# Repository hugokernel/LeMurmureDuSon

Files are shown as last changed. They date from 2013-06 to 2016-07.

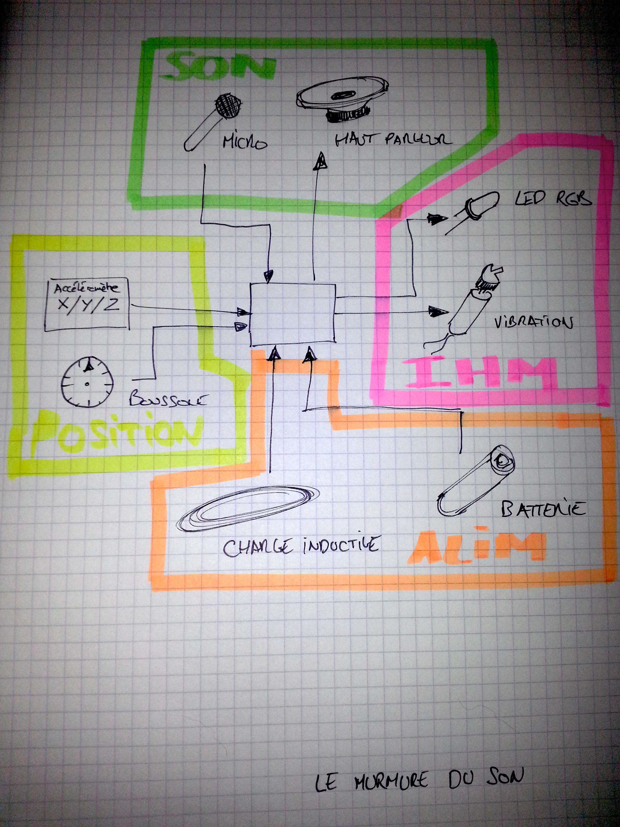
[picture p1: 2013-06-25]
doc/overview.jpg

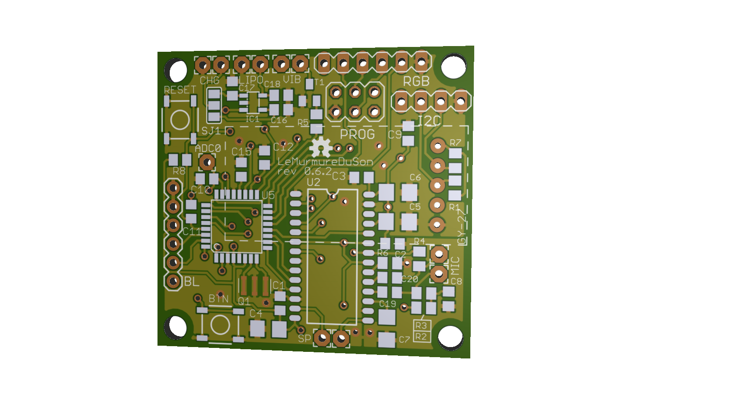
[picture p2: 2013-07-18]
export/img/0.6.2/gerber.png

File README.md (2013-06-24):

LeMurmureDuSon
==============

Projet de l'équipe nº1 du Museolab 2013 : Le murmure du son

Développement d'un post'it vocal sous la forme d'un cube

Caractéristiques
----------------

- 1 message enregistrable par face
- 1 texture différente par face
- Chaque message est limité à 6 secondes
- Possibilité d'enregistrement d'un nouveau message sur chaque face
- Charge par induction
- Détection de la face exposée vers le haut (accéléromètre)
- Le cube est translucide
- 1 vibreur
- Éclairage par 1 ou plusieurs led RGB
- Sur batterie
- Réalisable en impression 3D

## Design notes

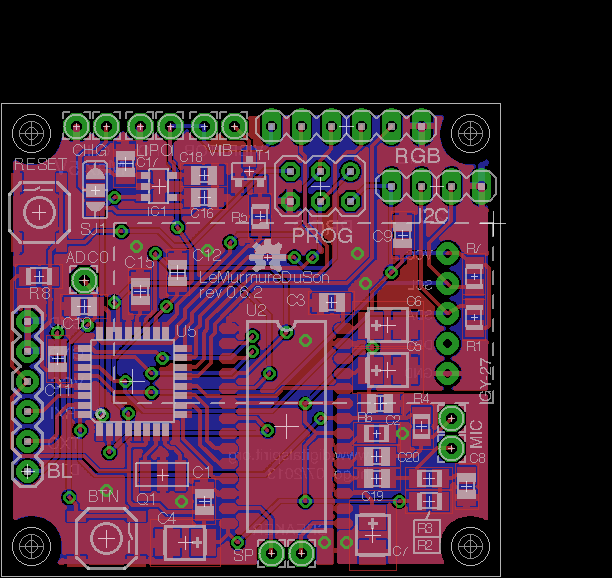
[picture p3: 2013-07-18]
export/img/0.6.2/pcb.png

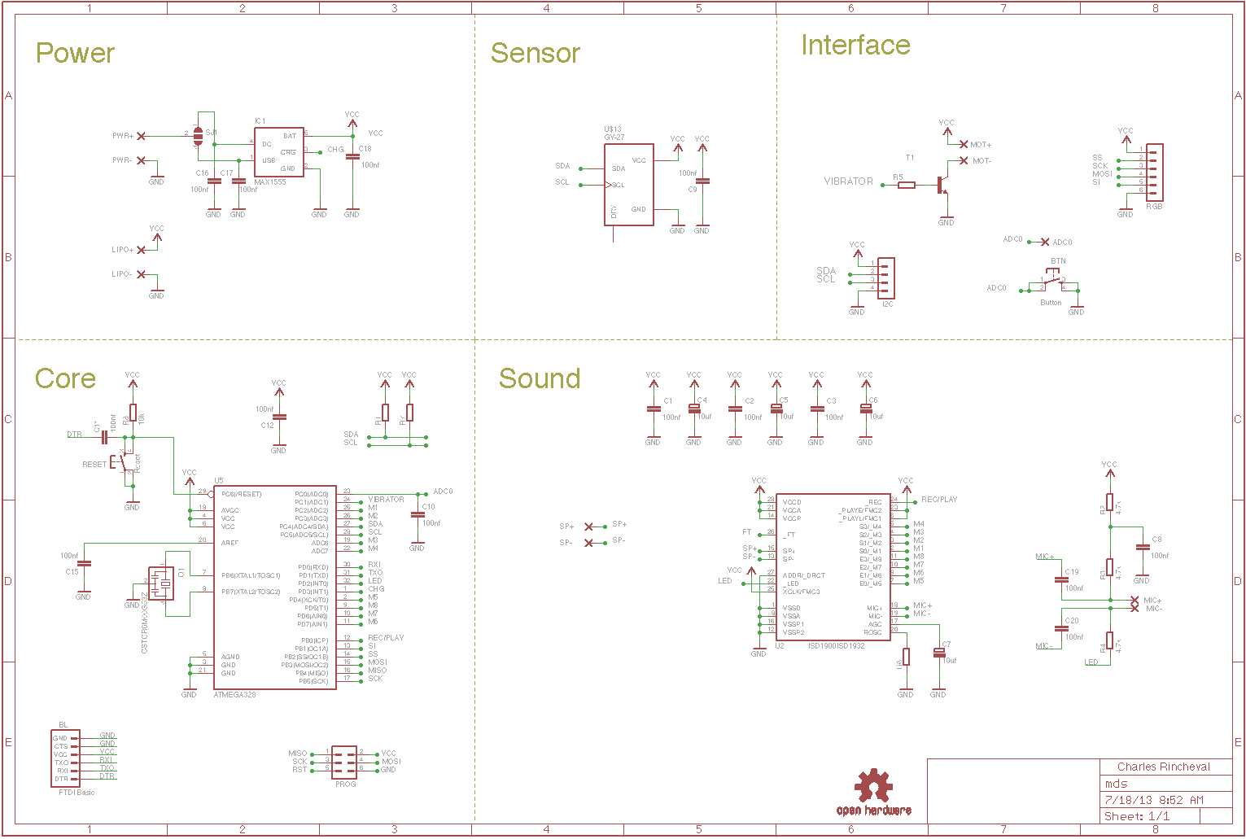
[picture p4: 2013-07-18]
export/img/0.6.2/schema.png

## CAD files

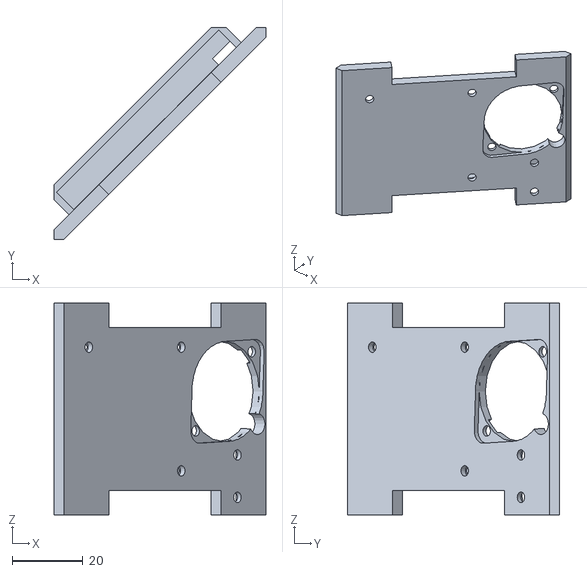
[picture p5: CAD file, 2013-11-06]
export/stl/support.stl
60.0 x 60.0 x 60.0

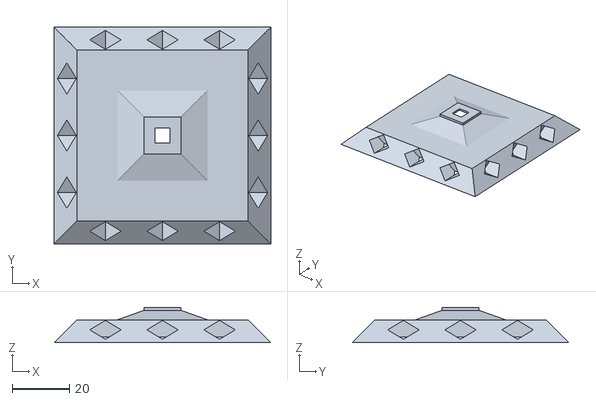
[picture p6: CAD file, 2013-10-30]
export/stl/4.stl
76.0 x 76.0 x 12.4

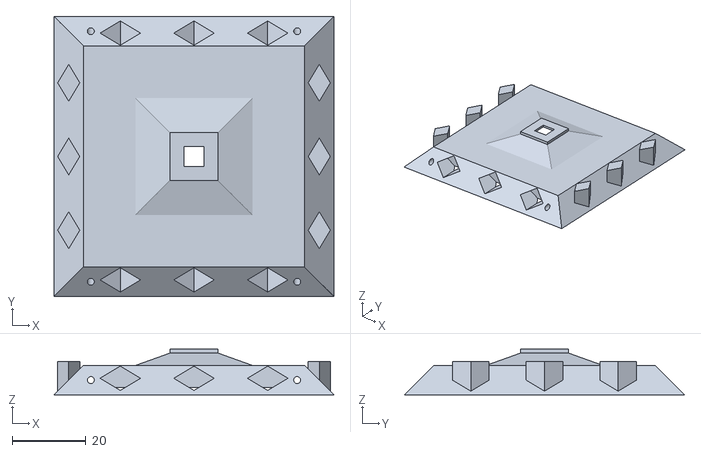
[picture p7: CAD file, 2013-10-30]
export/stl/2.stl
76.0 x 76.0 x 12.4

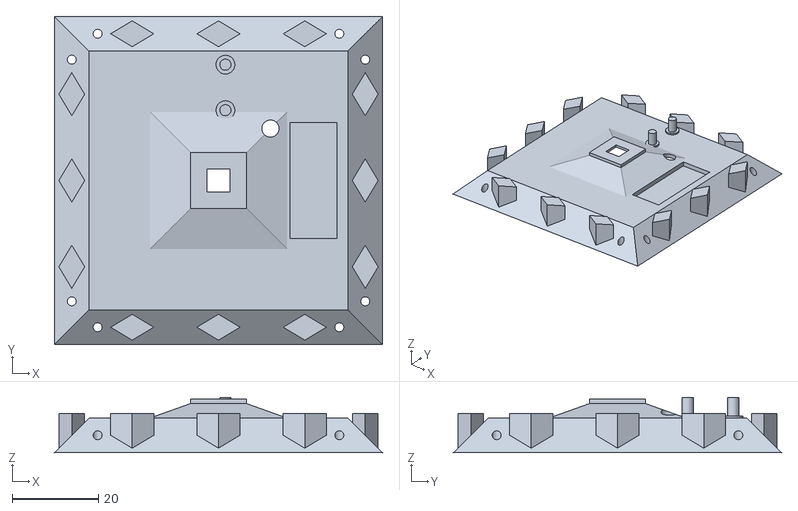
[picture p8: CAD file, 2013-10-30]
export/stl/0.stl
76.0 x 76.0 x 12.8

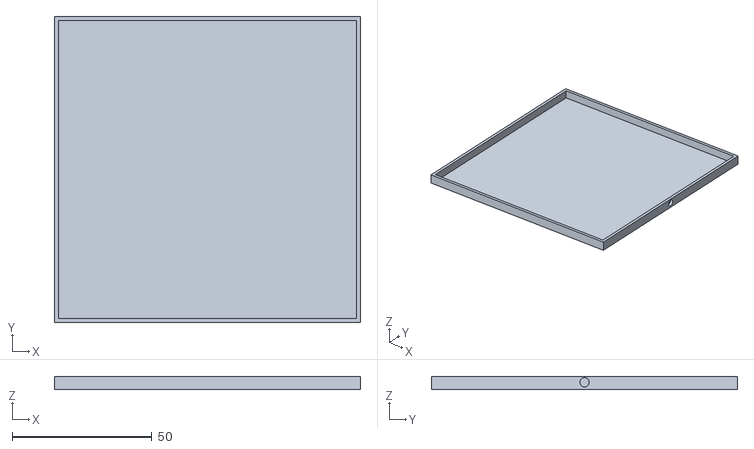
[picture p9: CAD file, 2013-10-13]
export/stl/base_enveloppe_cable.stl
109.4 x 109.4 x 4.70

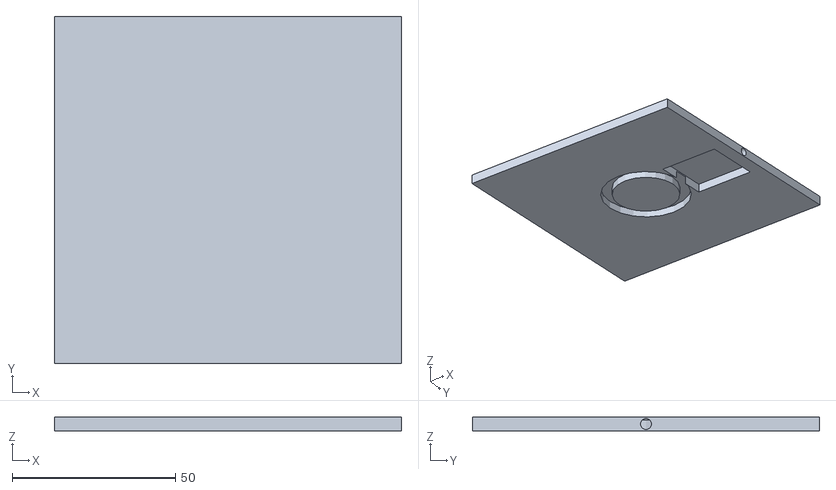
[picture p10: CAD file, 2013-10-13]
export/stl/base_plate_cable.stl
106.4 x 106.4 x 4.20

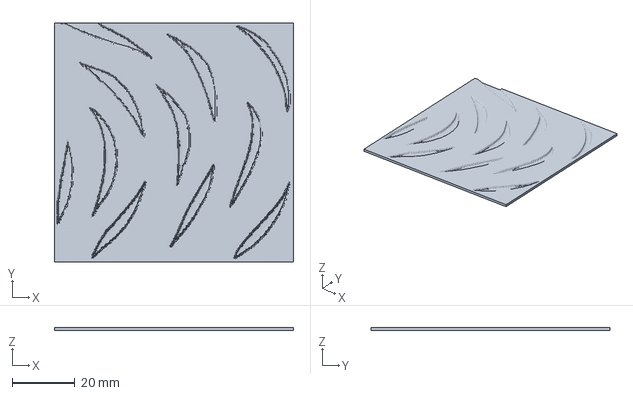
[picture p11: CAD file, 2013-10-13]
export/stl/pattern_5.amf
76.0 x 76.0 x 1.00 mm

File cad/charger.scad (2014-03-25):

use <cube.scad>

SIZE = 76;

coeff = 1.4;
thickness = 4.2;
size = SIZE * coeff;

module cable() {
    // Cable
    translate([SIZE / 2, 0, 0]) {
        rotate([0, 90, 0]) {
            cylinder(r = thickness / 2 - thickness * 0.1, h = 20);
        }
    }
}

module usb() {
    length = 8;
    width = 7.2;
    thickness = 2.9;

    // Usb
    translate([size / 2 - width / 2 + 0.001, 0, 0]) {//-thickness / 2 - 0.01]) {
        cube(size = [width, length, thickness], center = true);
    }
}

module enveloppe(usb = true) {
    base_thickness = 0.5;
    gain = 3;
    sizee = size + gain;
    clear = 0;
    translate([0, 0, - thickness / 2 - base_thickness / 2]) {
        cube(size = [sizee, sizee, base_thickness], center = true);
    }

    translate([0, 0, 0]) {
        difference() {
            cube(size = [sizee, sizee, thickness], center = true);
            translate([0, 0, 0.1]) {
                cube(size = [size + clear, size + clear, thickness], center = true);
            }

            translate([gain / 2, 0, 0]) {
                if (usb) {
                    usb();
                } else {
                    cable();
                }
            }
        }
    }
}

module base(usb = true) {

    module plate() {
        difference() {
            cube(size = [size, size, thickness], center = true);

            //translate([0, 0, -thickness / 2 - 0.01]) {
            translate([0, 0, -3]) {
                coil(hole = false, height = thickness);
            }

            //translate([33, 0, -thickness / 2 - 0.01]) {
            translate([33, 0, -0.3]) {
                cube(size = [28, 25, thickness], center = true);
            }

            if (usb) {
                usb();
            } else {
                cable();
            }
        }
    }

    plate();
    //enveloppe();
}

intersection() {
    /*
    translate([50, 0, 0]) {
        cube([40, 40, 20], center = true);
    }
    */
    //base();
    enveloppe();
}

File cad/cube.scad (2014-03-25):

use <lib/Spiff.scad>;
use <lib/mx.scad>;

$fn = 20;

SIZE = 76;
RIDGE_WIDTH = 8;

THICKNESS = 3;

HOLE_DIAMETER = 2 + .1;

ELEC_WIDTH = 42.3;
ELEC_LENGTH = 40;
ELEC_THICKNESS = 0.8;

ELEC_SUPPORT_WIDTH = 37;
ELEC_SUPPORT_LENGTH = 35;
ELEC_HOLE_DIAMETER = 3;

GY27_WIDTH = 15.55;
GY27_LENGTH = 32.55;
GY27_THICKNESS = 1.6;
GY27_HEIGHT = 3.8;
GY27_HOLE_DIAMETER = 3;

REFLECTOR_HEIGHT = 12;

DEBUG = false;

module coil(hole = true, height = 1.7) {
    ediameter = 39;
    idiameter = 29.1;
    difference() {
        cylinder(r = ediameter / 2, h = height);

        translate([0, 0, -2]) {
            cylinder(r = idiameter / 2, h = 10);
        }
    }

    if (hole) {
        translate([(ediameter - (ediameter - idiameter) / 2) / 2, 0, 0]) {
            cylinder(r = 2, h = 12);
        }
    }
}

module charger() {
    cube(size = [9.9, 24.5, 4], center = true);
}

module gy27(support = false) {
    positions = [
        [GY27_WIDTH / 2 - 2.5, GY27_LENGTH / 2 - 3, 0],
        [-GY27_WIDTH / 2 + 2.5, GY27_LENGTH / 2 - 3, 0],
    ];

    if (support) {
        for (pos = positions) {
            translate([pos[0], pos[1], pos[2] - 0.25]) {
                cylinder(r = GY27_HOLE_DIAMETER / 2 + 0.7, h = 0.5, center = true);
                translate([0, 0, 2]) {
                    cylinder(r = GY27_HOLE_DIAMETER / 2 - 0.2, h = 5, center = true);
                }
            }
        }
    } else {
        difference() {
            cube(size = [GY27_WIDTH, GY27_LENGTH, GY27_THICKNESS], center = true);
            for (pos = positions) {
                translate(pos) {
                    cylinder(r = GY27_HOLE_DIAMETER / 2, h = 10, center = true);

                    if ($children) {
                        for (i = [0 : $children - 1]) {
                            child(0);
                        }
                    }
                }
            }
        }
    }
}

module electronic(version = 1, diff = false) {
    module bluetooth() {
        width = 10;
        length = 15;
        translate([-ELEC_WIDTH / 2, -ELEC_LENGTH / 2 + 16 / 2 - 0.5, 0]) {
            cube(size = [width, length, ELEC_THICKNESS], center = true);
        }
    }

    module holes() {
        for(pos = [
            [ELEC_SUPPORT_WIDTH / 2, ELEC_SUPPORT_LENGTH / 2, -5, 2],
            [-ELEC_SUPPORT_WIDTH / 2, ELEC_SUPPORT_LENGTH / 2, -5, 2],
            [ELEC_SUPPORT_WIDTH / 2, -ELEC_SUPPORT_LENGTH / 2, -5, 2],
            [-ELEC_SUPPORT_WIDTH / 2, -ELEC_SUPPORT_LENGTH / 2, -5, 1],
        ]) {
            if (pos[3] >= version) {
                translate([pos[0], pos[1], -10]) {
                    cylinder(r = ELEC_HOLE_DIAMETER / 2, h = 10);
                }

                if ($children) {
                    translate([pos[0], pos[1], 0]) {
                        child(0);
                    }
                }
            }
        }
    }

    module body() {
        cube(size = [ELEC_WIDTH, ELEC_LENGTH, ELEC_THICKNESS], center = true);
        if (version == 2) {
            bluetooth();
        }
    }

    if (diff) {
        //body();
        holes() {
            if ($children) {
                child(0);
            }
        };
    } else {
        difference() {
            body();
            holes();
        }
    }
}

LIPO_WIDTH = 40;
LIPO_LENGTH = 65;
LIPO_THICKNESS = 7;

module lipo() {
    cube(size = [LIPO_LENGTH, LIPO_WIDTH, LIPO_THICKNESS], center = true);
}

SPEAKER_DIAMETER = 28.5;
module speaker() {
    thickness = 5;
    clear = 0.5;

    module holes() {
        for (pos = [
            [31.7 / 2, 0, 0],
            [-31.7 / 2, 0, 0],
        ]) {
            translate(pos) {
                child(0);
            }
        }
    }

    hull() {
        cylinder(r = SPEAKER_DIAMETER / 2, h = thickness, center = true);
        holes() {
            cylinder(r = 3.5, h = thickness, center = true);
        }
    }

    holes() {
        child(0);
    }
}

module vibrator() {
    translate([29, -25, 0]) {
        cylinder(r = 1.5, h = 10, center = true);
        translate([0, 12, 0]) {
            cylinder(r = 1.5, h = 10, center = true);
        }

        hull() {
            translate([0, 0, -2]) {
                cylinder(r = 3.5, h = 5, center = true);
            }

            translate([0, 12, -2]) {
                cylinder(r = 3.5, h = 5, center = true);
            }
        }
    }
}

module support() {

    thickness = 4;
    height = SIZE - RIDGE_WIDTH * 2;
    size = sqrt(pow(height, 2) + pow(height, 2));
    ear = 20;

    lipo_support_thickness = 3;

    module lipo_support() {
        translate([0, -LIPO_WIDTH / 2 - lipo_support_thickness / 2 + 2, - thickness / 2 - LIPO_THICKNESS / 2]) {
            cube(size = [LIPO_LENGTH + thickness, lipo_support_thickness + thickness, LIPO_THICKNESS + thickness], center = true);
        }
    }

    module _speaker() {
        translate([25, 5, 6]) {
            cylinder(r = SPEAKER_DIAMETER / 2, h = 50, center = true);
            rotate([0, 0, 45]) {
                color("ORANGE") speaker() {
                    child(0);
                }
            }

            /*
            translate([8, SPEAKER_DIAMETER / 2 + 5, 0]) {
                cylinder(r = 3, h = 50, center = true);
            }
            */
        }

        translate([37, -SPEAKER_DIAMETER / 2 + 10, 0]) {
            cylinder(r = 3, h = 50, center = true);
        }
    }

/*
    module _gy27(support = false) {
        rotate([90, 45, 0]) {
            translate([21, -12, height / 2]) {
                gy27(support);
            }
        }
    }
*/
    rotate([90, 0, 45]) {
        difference() {

            union() {
                // Helper
                //%cube(size = [size, height, 1], center = true);

                cube(size = [size, height - REFLECTOR_HEIGHT - 2, thickness], center = true);
                for (pos = [
                    [size / 2 - ear / 2, height / 2 - ear / 2, 0],
                    [-size / 2 + ear / 2, height / 2 - ear / 2, 0],
                    [size / 2 - ear / 2, -height / 2 + ear / 2, 0],
                    [-size / 2 + ear / 2, -height / 2 + ear / 2, 0]
                ]) {
                    translate(pos) {
                        cube(size = [ear, ear, thickness], center = true);
                    }
                }

                if (DEBUG) {
                    translate([-12, 0, thickness]) {
                        color("RED") electronic(2);
                    }
                }

                if (DEBUG) {
                    translate([0, 0, - thickness / 2 - LIPO_THICKNESS / 2]) {
                        //%color("GREY") lipo();
                    }
                }

                lipo_support();

                //_speaker();
            }

            for (pos = [
                [0, SIZE / 2 - RIDGE_WIDTH / 2, 0, 45, 90],
                [0, - SIZE / 2 + RIDGE_WIDTH / 2, 0, -45, 90],
                [0, SIZE / 2 - RIDGE_WIDTH / 2, 0, -45, 90],
                [0, - SIZE / 2 + RIDGE_WIDTH / 2, 0, 45, 90]
            ]) {
                rotate([pos[3], 0, pos[4]]) {
                    translate([pos[0], pos[1], pos[2]]) {
                        cube(size = [SIZE, RIDGE_WIDTH, SIZE], center = true);
                    }
                }
            }

            translate([-12, 0, thickness]) {
                electronic(2, true) {
                    union() {
                        translate([0, 0, -4.9]) {
                            m3_nut();
                        }
                    }
                }
            }

            translate([0, 0, - thickness / 2 - LIPO_THICKNESS / 2 - .005]) {
                lipo();
            }

            translate([0, 0, -3]) {
                _speaker() {
                    union() {
                        cylinder(r = 1.5, h = 50, center = true);
                        translate([0, 0, -4.9]) {
                            m3_nut();
                            //cylinder(r = 3.5, h = 5, center = true);
                        }
                    }
                }
            }

            vibrator();
        }
    }
}

NOTHING = -1;
MALE = true;
FEMALE = false;

module front(index, mark, connection) {
    edge_size = SIZE / 2 * sqrt(2);

    module _charger() {
        rotate([0, 0, -45]) {
            translate([22, 0, 8.5]) {
                scale([1.1, 1.1, 1]) {
                    charger();
                }
            }
        }
    }

    module plot(add, substract = true) {
        width = 4;
        length = 10;
        //height = 8;
        height = 5;

        clear = 0.4;
        clear_height = 8;
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

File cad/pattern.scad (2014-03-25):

$fn = 20;

SIZE = 76;
THICKNESS = 1;

sizes = [
    [ 76.3, 76.5 ],     // 0
    [ 76.5, 76.2 ],     // 1
    [ 77.94, 77.94 ],   // 2
    [ 77.94, 77.94 ],   // 3
    [ 77.94, 76 ],      // 4
    [ 77.94, 76 ],      // 5
];

RIDGE_WIDTH = 8;
HOLE_DIAMETER = 2 + .5;

module holes() {
    rotate([0, 0, 45]) {
        for(pos = [
            [SIZE / 2 - RIDGE_WIDTH - 2, SIZE / 2 - RIDGE_WIDTH / 2, 0],
            [-SIZE / 2 + RIDGE_WIDTH + 2, SIZE / 2 - RIDGE_WIDTH / 2, 0],
            [SIZE / 2 - RIDGE_WIDTH - 2, -SIZE / 2 + RIDGE_WIDTH / 2, 0],
            [-SIZE / 2 + RIDGE_WIDTH + 2, -SIZE / 2 + RIDGE_WIDTH / 2, 0],
        ]) {
            translate(pos) {
                cylinder(r = HOLE_DIAMETER / 2, h = 100, center = true);

                if ($children) {
                    for (i = [0 : $children - 1]) {
                        child(0);
                    }
                }
            }
        }
    }
}

module bump(index, size = SIZE, thick = THICKNESS) {
    stl_width = 300;
    stl_thickness = 10;
    thickness = 1;

    coeff_w = stl_width / sizes[index][0];
    coeff_l = stl_width / sizes[index][1];
    coeff_t = stl_thickness / thick;

    translate([stl_width / coeff_w / 2, stl_width / coeff_l / 2, thickness / 2]) {
        scale([1 / coeff_w, 1 / coeff_l, 1 / coeff_t]) {
            import(str("pattern/", index, ".stl"));
        }
    }

    if (index == 5) {
        translate([0, 0, thickness / 2 - 0.4]) {
            cube(size = [sizes[index][0], sizes[index][1], 0.2], center = true);
        }
    } else {
        translate([0, 0, thickness / 2 - 0.5]) {
            cube(size = [sizes[index][0], sizes[index][1], 1], center = true);
        }
    }
}



module faces(which = -1, offset = 30) {

    nut_head_diameter = 4.6; // Before : 4: serré, 5: too large
    nut_head_height = 1.3;

    offset = offset + SIZE / 2;

    difference() {
        for (data = [
            [ 0, [0, 0, -offset],   [180, 0, 0], "RED" ],
            [ 1, [0, 0, offset],    [0, 0, 0]   ],
            [ 2, [offset, 0, 0],    [0, 90, 0], "BLUE" ],
            [ 3, [-offset, 0, 0],   [0, -90, 0] ],
            [ 4, [0, -offset, 0],   [90, 0, 0]  ],
            [ 5, [0, offset, 0],    [-90, 0, 0] ]
        ]) {
            if (which == -1 || which == data[0]) {
                translate(data[1]) {
                    rotate(data[2]) {
                        //color(data[3])
                        bump(data[0]);
                    }
                }
            }
        }

        rotate([0, 0, 45]) {
            holes() {
                if (which == 0) {
                    translate([0, 0, -(SIZE / 2 + nut_head_height + THICKNESS)]) {
                        cylinder(r = nut_head_diameter / 2, h = 2);
                    }
                } else if (which == 1) {
                    translate([0, 0, SIZE / 2 - nut_head_height + THICKNESS]) {
                        cylinder(r = nut_head_diameter / 2, h = 2);
                    }
                }
            }
        }
    
        if (which == 1) {
            // Mic hole
            translate([0, -20, 0]) {
                cylinder(r = 2, h = 200);
            }
        }
    }
}

//bump(1, SIZE);

%cube(size = [SIZE, SIZE, SIZE], center = true);

faces(4, 0);

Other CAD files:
export/stl/1.stl
export/stl/5.stl
export/stl/3.stl

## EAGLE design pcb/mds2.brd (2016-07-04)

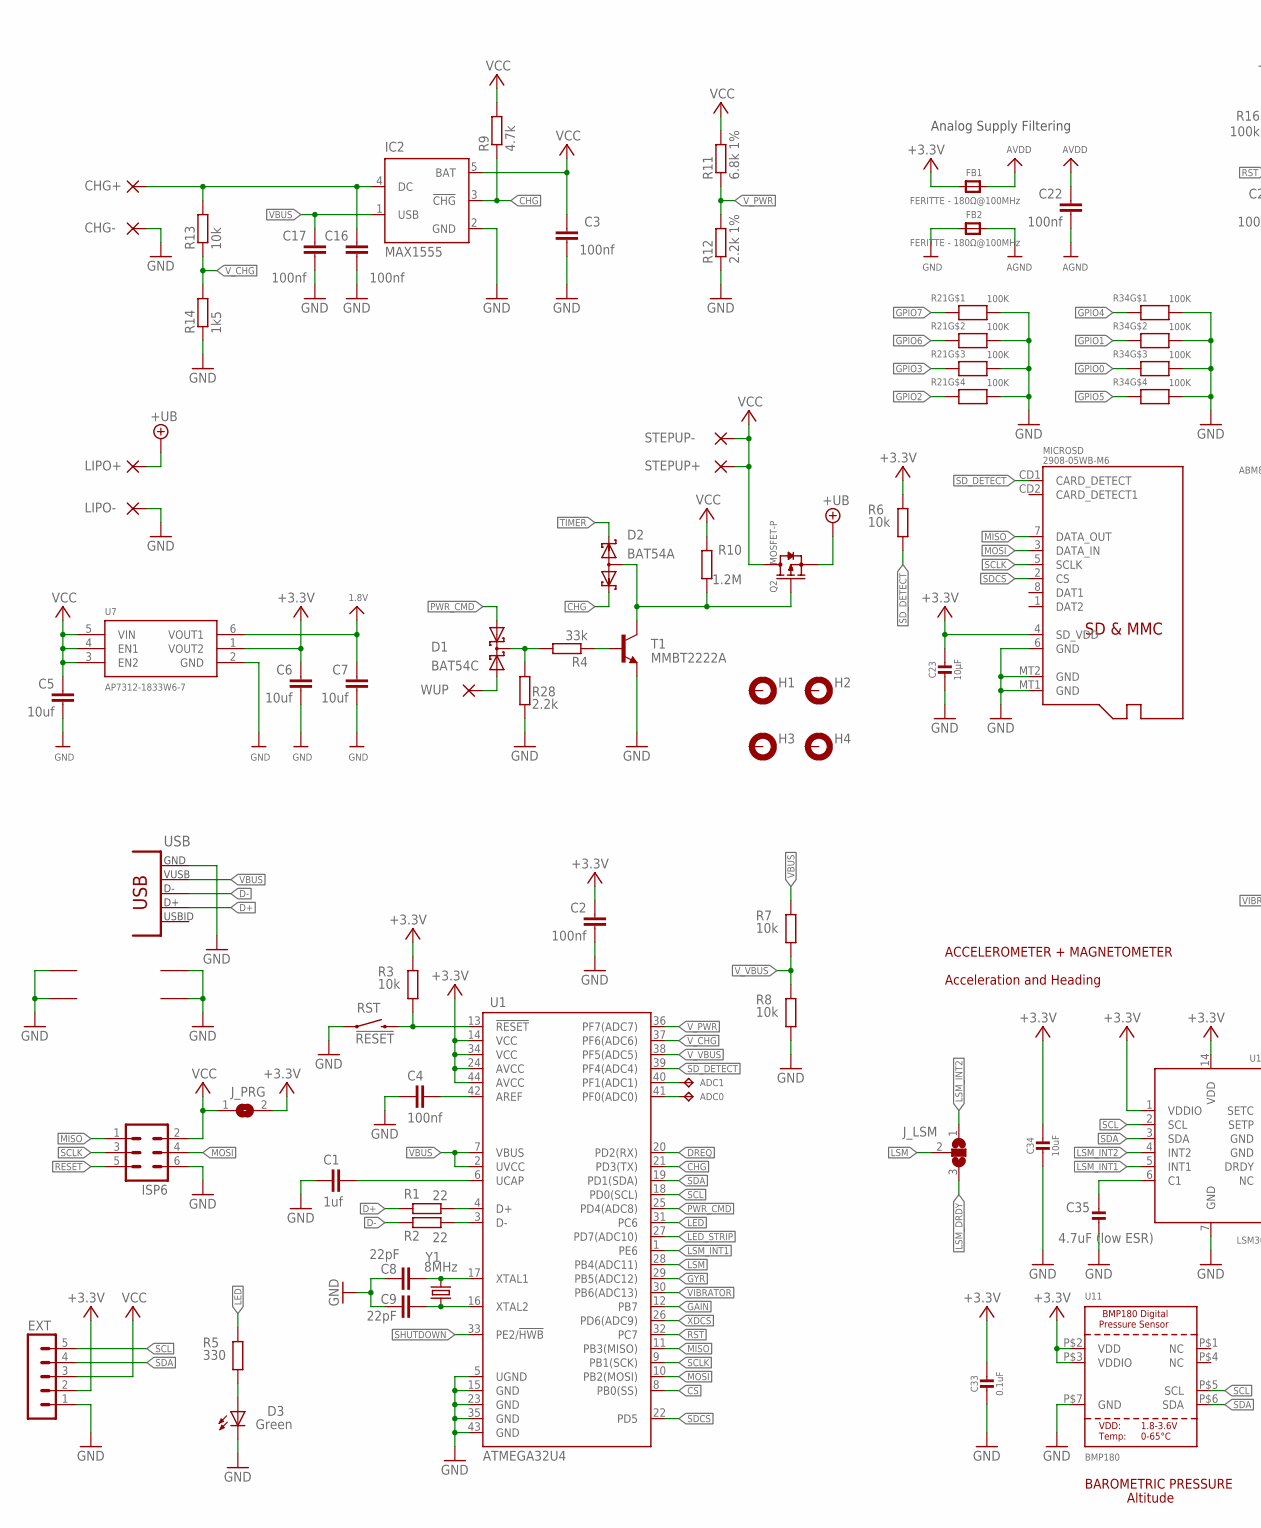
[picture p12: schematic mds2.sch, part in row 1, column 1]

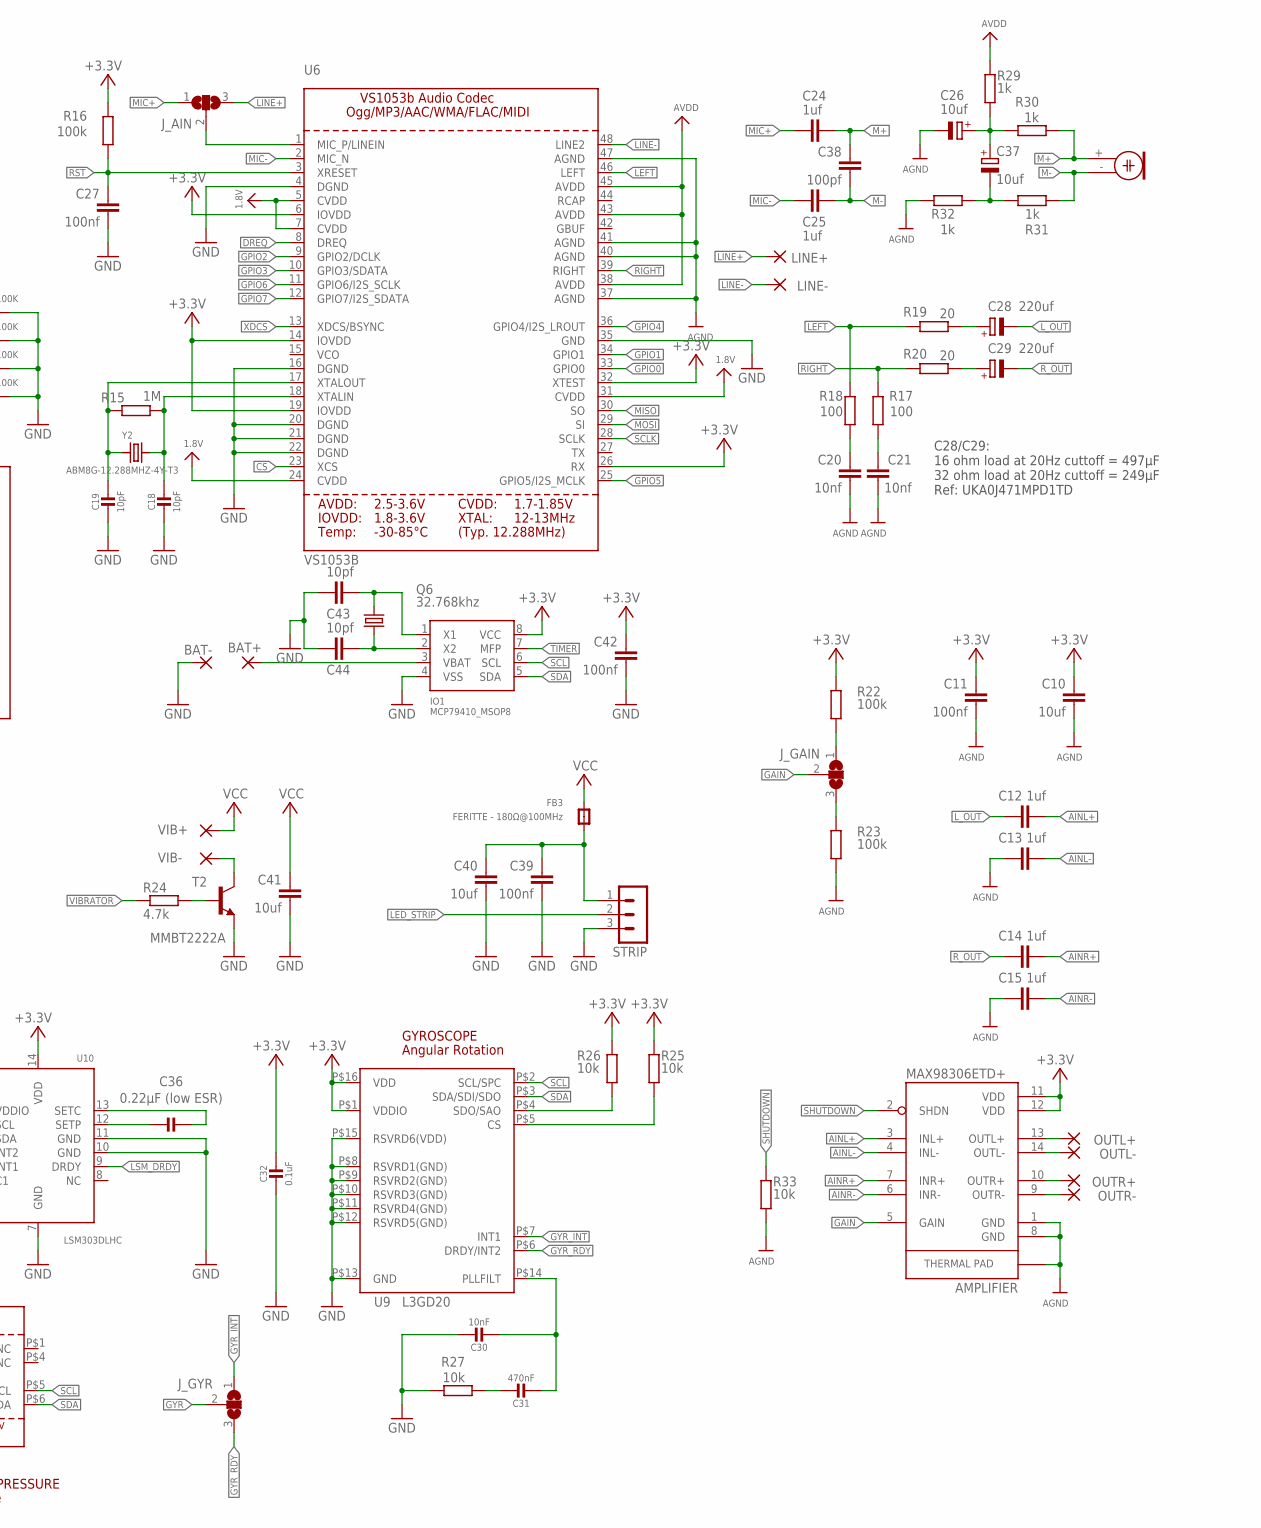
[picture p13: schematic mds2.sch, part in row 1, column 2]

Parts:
ADC0, ADC1: TPB1,27; B1,27
AMPLIFIER: MAX98306ETD+; 14-TDFN
BAT+: 1,6/0,8
BAT-: 1,6/0,8
C1, C12, C13, C14, C15, C24, C25: 1uf; C0805
C2, C3, C4, C11, C16, C17, C22, C27, C39, C42: 100nf; C0805
C5, C6, C7, C10, C40, C41: 10uf; C0805
C8, C9: 22pF; 0402-CAP
C18, C19: 10pF; _0805MP
C20, C21: 10nf; C0805
C23: 10µF; _0805MP
C26, C37: 10uf; PANASONIC_C
C28, C29: 220uf; PANASONIC_D
C30: 10nF; _0805MP
C31: 470nF; _0805MP
C32, C33: 0.1uF; _0805MP
C34: 10uF; _0805MP
C35: 4.7uF (low ESR); _0805MP
C36: 0.22µF (low ESR); _0805MP
C38: 100pf; C0805
C43, C44: 10pf; C0805
CHG+: 2,15/1,0
CHG-: 2,15/1,0
D1: BAT54C; SOT23
D2: BAT54A; SOT23
D3: Green; LED-0603
EXT: MA05-1
FB1, FB2, FB3: FERITTE - 180Ω@100MHz; _0805MP
H1, H2, H3, H4: MOUNT-PAD-ROUND3.0; 3,0-PAD
IC2: MAX1555; SOT23-5L
IO1: MCP79410_MSOP8; MSOP8
ISP6: MA03-2
J_AIN: SJ2W; SJ_2
J_GAIN: SJ2W; SJ_2
J_GYR: SJ2W; SJ_2
J_LSM: SJ2W; SJ_2
J_PRG: SJ
LINE+: 1,6/0,8
LINE-: 1,6/0,8
LIPO+: 2,15/1,0
LIPO-: 2,15/1,0
MIC: ELECTRET_MICROPHON-TOM-1545P-R; TOM-1545P-R
MICROSD: 2908-05WB-M6; MICROSD
OUTL+: 2,15/1,0
OUTL-: 2,15/1,0
OUTR+: 2,15/1,0
OUTR-: 2,15/1,0
Q2: MOSFET-P; SOT23
Q6: 32.768khz; TC26H
R1, R2: 22; M0805
R3, R6, R7, R8, R13, R25, R26, R27, R33: 10k; M0805
R4: 33k; M0805
R5: 330; M0805
R9, R24: 4.7k; M0805
R10: 1.2M; M0805
R11: 6.8k 1%; M0805
R12: 2.2k 1%; M0805
R14: 1k5; M0805
R15: 1M; M0805
R16, R22, R23: 100k; M0805
R17, R18: 100; M0805
R19, R20: 20; M0805
R21, R34: 100K; RESPACK_4X0603
R28: 2.2k; M0805
R29, R30, R31, R32: 1k; M0805
RST: !RESET; TACTILE_SWITCH_SMD
STEPUP+: 2,15/1,0
STEPUP-: 2,15/1,0
STRIP: MA03-1
T1, T2: MMBT2222A; SOT23-BEC
U1: ATMEGA32U4; QFN-44-NOPAD
U6: VS1053B; LQFP48
U7: AP7312-1833W6-7; SOT23-6
U9: L3GD20; L3G4200D_LGA16L
U10: LSM303DLHC; LGA14
U11: BMP180; BMP180_EXTENDED
USB: CON-USB-F-MICRO-B; CONN_USB_MICRO-B
VIB+: 1,6/0,8
VIB-: 1,6/0,8
WUP: 1,6/0,8
Y1: 8MHz; CRYSTAL-SMD-5X3
Y2: ABM8G-12.288MHZ-4Y-T3; CRYSTAL_3.2X2.5

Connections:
1.8V: C7.2, U6.5 (CVDD), U6.7 (CVDD), U6.24 (CVDD), U6.31 (CVDD), U7.6 (VOUT1)
+3V3: AMPLIFIER.11 (VDD), AMPLIFIER.12 (VDD), C2.2, C6.2, C10.2, C11.2, C23.1, C32.1, C33.1, C34.1, C42.2, EXT.2, FB1.1, IO1.8 (VCC), J_PRG.2, MICROSD.4 (SD_VDD), R3.1, R6.1, R16.2, R22.2, R25.2, R26.2, U1.14 (VCC), U1.24 (AVCC), U1.34 (VCC), U1.44 (AVCC), U6.6 (IOVDD), U6.14 (IOVDD), U6.19 (IOVDD), U6.26 (RX), U6.32 (XTEST), U7.1 (VOUT2), U9.P$1 (VDDIO), U9.P$16 (VDD), U10.1 (VDDIO), U10.14 (VDD), U11.P$2 (VDD), U11.P$3 (VDDIO)
+UB: LIPO+.1, Q2.2 (S)
AGND: AMPLIFIER.1 (GND), AMPLIFIER.8 (GND), AMPLIFIER.15 (GND), C10.1, C11.1, C13.2, C15.2, C20.1, C21.1, C22.1, C26.-, FB2.2, R23.1, R32.1, R33.1, U6.37 (AGND), U6.40 (AGND), U6.41 (AGND), U6.47 (AGND)
AINL+: AMPLIFIER.3 (INL+), C12.1
AINL-: AMPLIFIER.4 (INL-), C13.1
AINR+: AMPLIFIER.7 (INR+), C14.1
AINR-: AMPLIFIER.6 (INR-), C15.1
AREF: C4.1, U1.42 (AREF)
AVDD: C22.2, FB1.2, R29.2, U6.38 (AVDD), U6.43 (AVDD), U6.45 (AVDD)
CHG: D2.2 (K2), IC2.3 (!CHG), R9.1, U1.21 (PD3(TX))
CS: U1.8 (PB0(SS)), U6.23 (XCS)
D+: R1.2, USB.P3 (D+)
D-: R2.2, USB.P2 (D-)
DREQ: U1.20 (PD2(RX)), U6.8 (DREQ)
GAIN: AMPLIFIER.5 (GAIN), J_GAIN.2, U1.12 (PB7)
GND: BAT-.1, C1.2, C2.1, C3.1, C4.2, C5.1, C6.1, C7.1, C8.2, C9.2, C16.1, C17.1, C18.2, C19.2, C23.2, C27.1, C30.1, C32.2, C33.2, C34.2, C35.2, C39.1, C40.1, C41.1, C42.1, C43.2, C44.2, CHG-.1, D3.C, EXT.1, FB2.1, IC2.2 (GND), IO1.4 (VSS), ISP6.6, LIPO-.1, MICROSD.6 (GND), MICROSD.MT1 (GND), MICROSD.MT2 (GND), R8.2, R12.1, R14.1, R21.5 (2), R21.6 (2), R21.7 (2), R21.8 (2), R27.1, R28.2, R34.5 (2), R34.6 (2), R34.7 (2), R34.8 (2), RST.1, STRIP.3, T1.E, T2.E, U1.5 (UGND), U1.15 (GND), U1.23 (GND), U1.35 (GND), U1.43 (GND), U6.4 (DGND), U6.16 (DGND), U6.20 (DGND), U6.21 (DGND), U6.22 (DGND), U6.35 (GND), U7.2 (GND), U9.P$8 (RSVRD1(GND)), U9.P$9 (RSVRD2(GND)), U9.P$10 (RSVRD3(GND)), U9.P$11 (RSVRD4(GND)), U9.P$12 (RSVRD5(GND)), U9.P$13 (GND), U9.P$15 (RSVRD6(VDD)), U10.7 (GND), U10.10 (GND), U10.11 (GND), U11.P$7 (GND), USB.BODY@1 (BODY), USB.BODY@2 (BODY), USB.BODY@3 (BODY), USB.BODY@4 (BODY), USB.P5 (GND)
GPIO0: R34.3 (1), U6.33 (GPIO0)
GPIO1: R34.2 (1), U6.34 (GPIO1)
GPIO2: R21.4 (1), U6.9 (GPIO2/DCLK)
GPIO3: R21.3 (1), U6.10 (GPIO3/SDATA)
GPIO4: R34.1, U6.36 (GPIO4/I2S_LROUT)
GPIO5: R34.4 (1), U6.25 (GPIO5/I2S_MCLK)
GPIO6: R21.2 (1), U6.11 (GPIO6/I2S_SCLK)
GPIO7: R21.1, U6.12 (GPIO7/I2S_SDATA)
GYR: J_GYR.2, U1.29 (PB5(ADC12))
GYR_INT: J_GYR.1, U9.P$7 (INT1)
GYR_RDY: J_GYR.3, U9.P$6 (DRDY/INT2)
LED: R5.1, U1.31 (PC6)
LED_STRIP: STRIP.2, U1.27 (PD7(ADC10))
LEFT: R17.2, R19.2, U6.46 (LEFT)
LEFT_FILTERED: C28.+, R19.1
LINE+: J_AIN.3, LINE+.1
LINE-: LINE-.1, U6.48 (LINE2)
LSM: J_LSM.2, U1.28 (PB4(ADC11))
LSM_DRDY: J_LSM.3, U10.9 (DRDY)
LSM_INT1: U1.1 (PE6), U10.5 (INT1)
LSM_INT2: J_LSM.1, U10.4 (INT2)
L_OUT: C12.2, C28.-
M+: C24.1, C38.2, MIC.+ (1), R30.2
M-: C25.1, C38.1, MIC.- (2), R31.1
MIC+: C24.2, J_AIN.1
MIC-: C25.2, U6.2 (MIC_N)
MISO: ISP6.1, MICROSD.7 (DATA_OUT), U1.11 (PB3(MISO)), U6.30 (SO)
MOSI: ISP6.4, MICROSD.3 (DATA_IN), U1.10 (PB2(MOSI)), U6.29 (SI)
unnamed: C9.1, U1.16 (XTAL2), Y1.1
unnamed: R1.1, U1.4 (D+)
unnamed: C16.2, CHG+.1, IC2.4 (DC), R13.2
unnamed: C8.1, U1.17 (XTAL1), Y1.3 (2)
unnamed: C1.1, U1.6 (UCAP)
unnamed: C39.2, C40.2, FB3.1, STRIP.1
unnamed: R2.1, U1.3 (D-)
unnamed: D3.A, R5.2
unnamed: R4.1, T1.B
unnamed: D2.3 (AA), Q2.1 (G), R10.1, T1.C
unnamed: D1.3 (CC), R4.2, R28.1
unnamed: D1.2 (A2), WUP.1
unnamed: R24.2, T2.B
unnamed: T2.C, VIB-.1
unnamed: ADC1.TP, U1.40 (PF1(ADC1))
unnamed: J_AIN.2, U6.1 (MIC_P/LINEIN)
unnamed: AMPLIFIER.14 (OUTL-), OUTL-.1
unnamed: J_GAIN.1, R22.1
unnamed: AMPLIFIER.13 (OUTL+), OUTL+.1
unnamed: C37.-, R31.2, R32.2
unnamed: ADC0.TP, U1.41 (PF0(ADC0))
unnamed: C44.1, IO1.2 (X2), Q6.1
unnamed: C26.+, C37.+, R29.1, R30.1
unnamed: AMPLIFIER.10 (OUTR+), OUTR+.1
unnamed: AMPLIFIER.9 (OUTR-), OUTR-.1
unnamed: J_GAIN.3, R23.2
unnamed: C43.1, IO1.1 (X1), Q6.2
unnamed: C19.1, R15.2, U6.17 (XTALOUT), Y2.1
unnamed: C18.1, R15.1, U6.18 (XTALIN), Y2.2
unnamed: C20.2, R17.1
unnamed: C21.2, R18.1
unnamed: BAT+.1, IO1.3 (VBAT)
unnamed: R25.1, U9.P$5 (CS)
unnamed: R26.1, U9.P$4 (SDO/SAO)
unnamed: C31.1, R27.2
unnamed: C30.2, C31.2, U9.P$14 (PLLFILT)
unnamed: C35.1, U10.6 (C1)
unnamed: C36.1, U10.12 (SETP)
unnamed: C36.2, U10.13 (SETC)
PWR_CMD: D1.1 (A1), U1.25 (PD4(ADC8))
RESET: ISP6.5, R3.2, RST.3 (2), U1.13 (!RESET)
RIGHT: R18.2, R20.2, U6.39 (RIGHT)
RIGHT_FILTERED: C29.+, R20.1
RST: C27.2, R16.1, U1.32 (PC7), U6.3 (XRESET)
R_OUT: C14.2, C29.-
SCL: EXT.5, IO1.6 (SCL), U1.18 (PD0(SCL)), U9.P$2 (SCL/SPC), U10.2 (SCL), U11.P$5 (SCL)
SCLK: ISP6.3, MICROSD.5 (SCLK), U1.9 (PB1(SCK)), U6.28 (SCLK)
SDA: EXT.4, IO1.5 (SDA), U1.19 (PD1(SDA)), U9.P$3 (SDA/SDI/SDO), U10.3 (SDA), U11.P$6 (SDA)
SDCS: MICROSD.2 (CS), U1.22 (PD5)
SD_DETECT: MICROSD.CD1 (CARD_DETECT), R6.2, U1.39 (PF4(ADC4))
SHUTDOWN: AMPLIFIER.2 (SHDN), R33.2, U1.33 (PE2/!HWB)
TIMER: D2.1 (K1), IO1.7 (MFP)
VBUS: C17.2, IC2.1 (USB), R7.1, U1.2 (UVCC), U1.7 (VBUS), USB.P1 (VUSB)
VCC: C3.2, C5.2, C41.2, EXT.3, FB3.2, IC2.5 (BAT), ISP6.2, J_PRG.1, Q2.3 (D), R9.2, R10.2, R11.2, STEPUP+.1, STEPUP-.1, U7.3 (EN2), U7.4 (EN1), U7.5 (VIN), VIB+.1
VIBRATOR: R24.1, U1.30 (PB6(ADC13))
V_CHG: R13.1, R14.2, U1.37 (PF6(ADC6))
V_PWR: R11.1, R12.2, U1.36 (PF7(ADC7))
V_VBUS: R7.2, R8.1, U1.38 (PF5(ADC5))
XDCS: U1.26 (PD6(ADC9)), U6.13 (XDCS/BSYNC)

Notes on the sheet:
Analog Supply Filtering
C28/C29: 16 ohm load at 20Hz cuttoff = 497µF 32 ohm load at 20Hz cuttoff = 249µF Ref: UKA0J471MPD1TD
GYROSCOPE
Angular Rotation
ACCELEROMETER + MAGNETOMETER
Acceleration and Heading
BAROMETRIC PRESSURE
Altitude

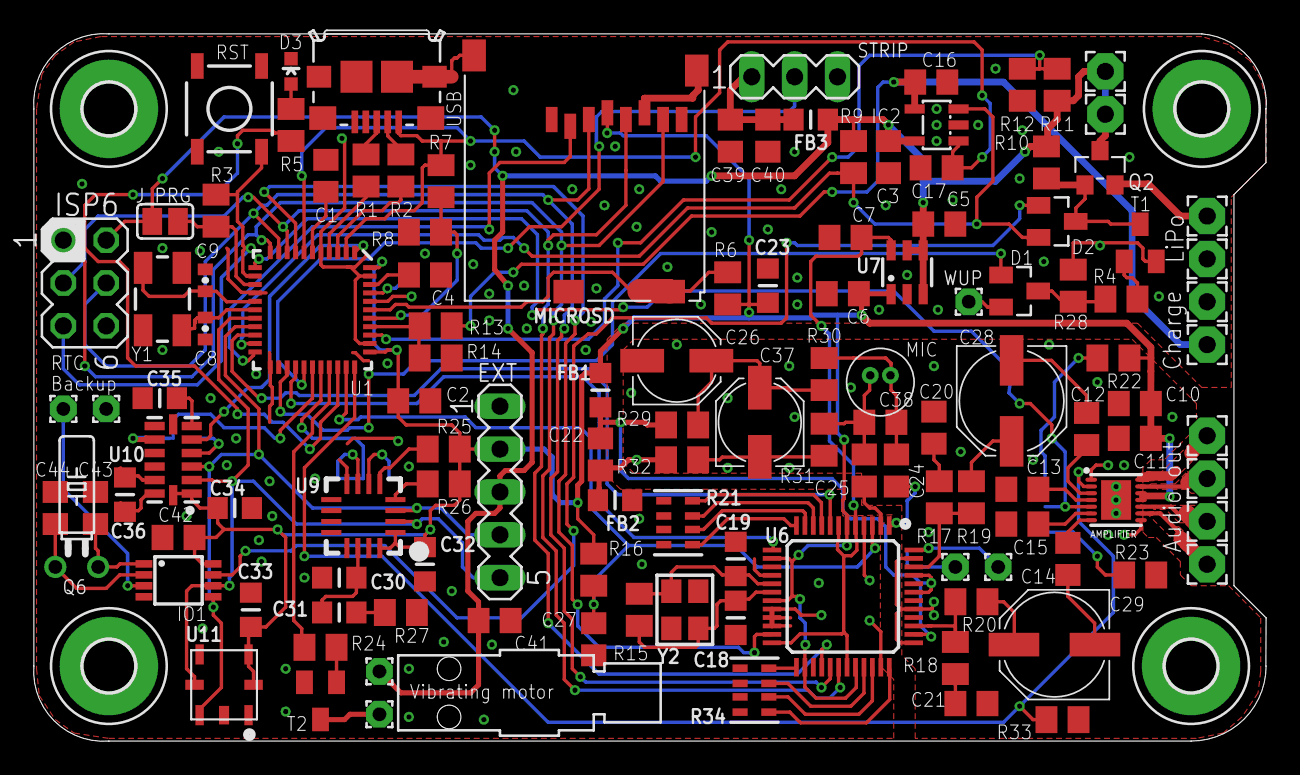
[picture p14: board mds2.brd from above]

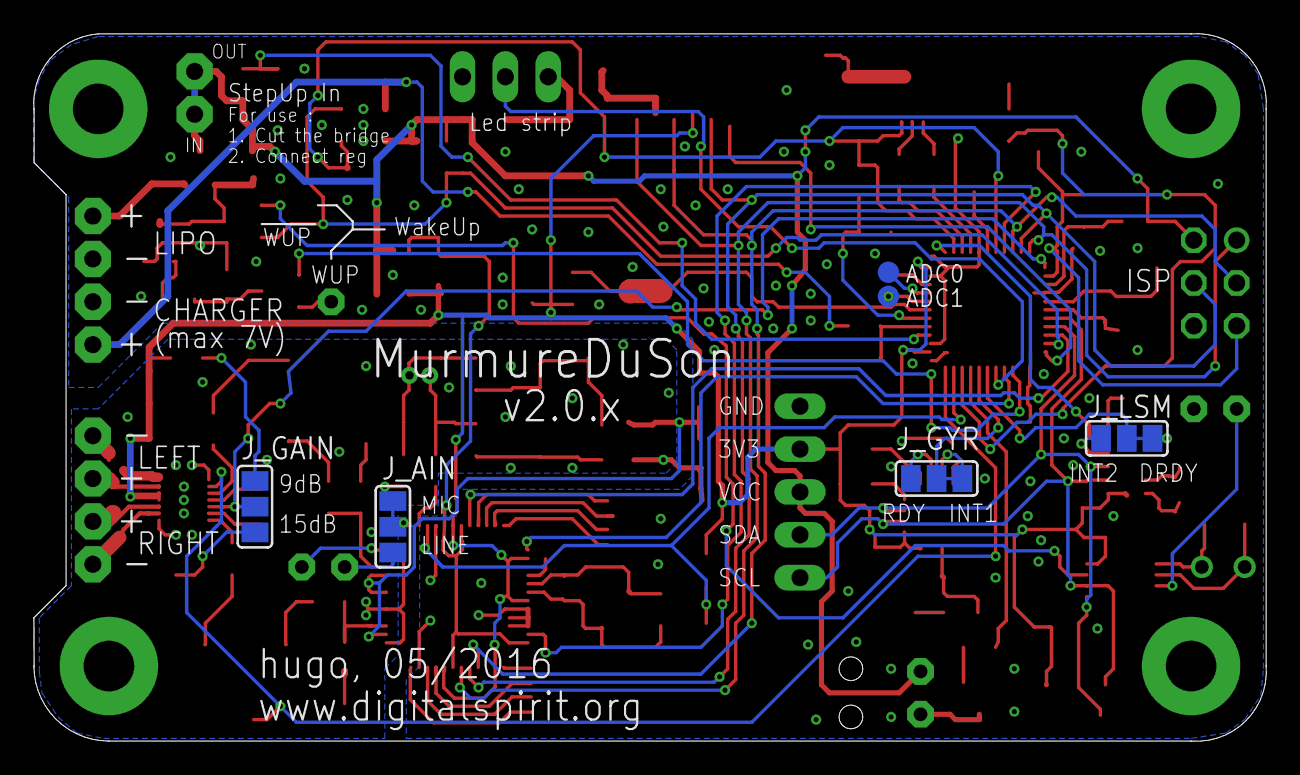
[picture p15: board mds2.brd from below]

Board: 2 copper layers, 73.0 x 41.9 mm, 134 parts (6 on the bottom side), 104 nets.

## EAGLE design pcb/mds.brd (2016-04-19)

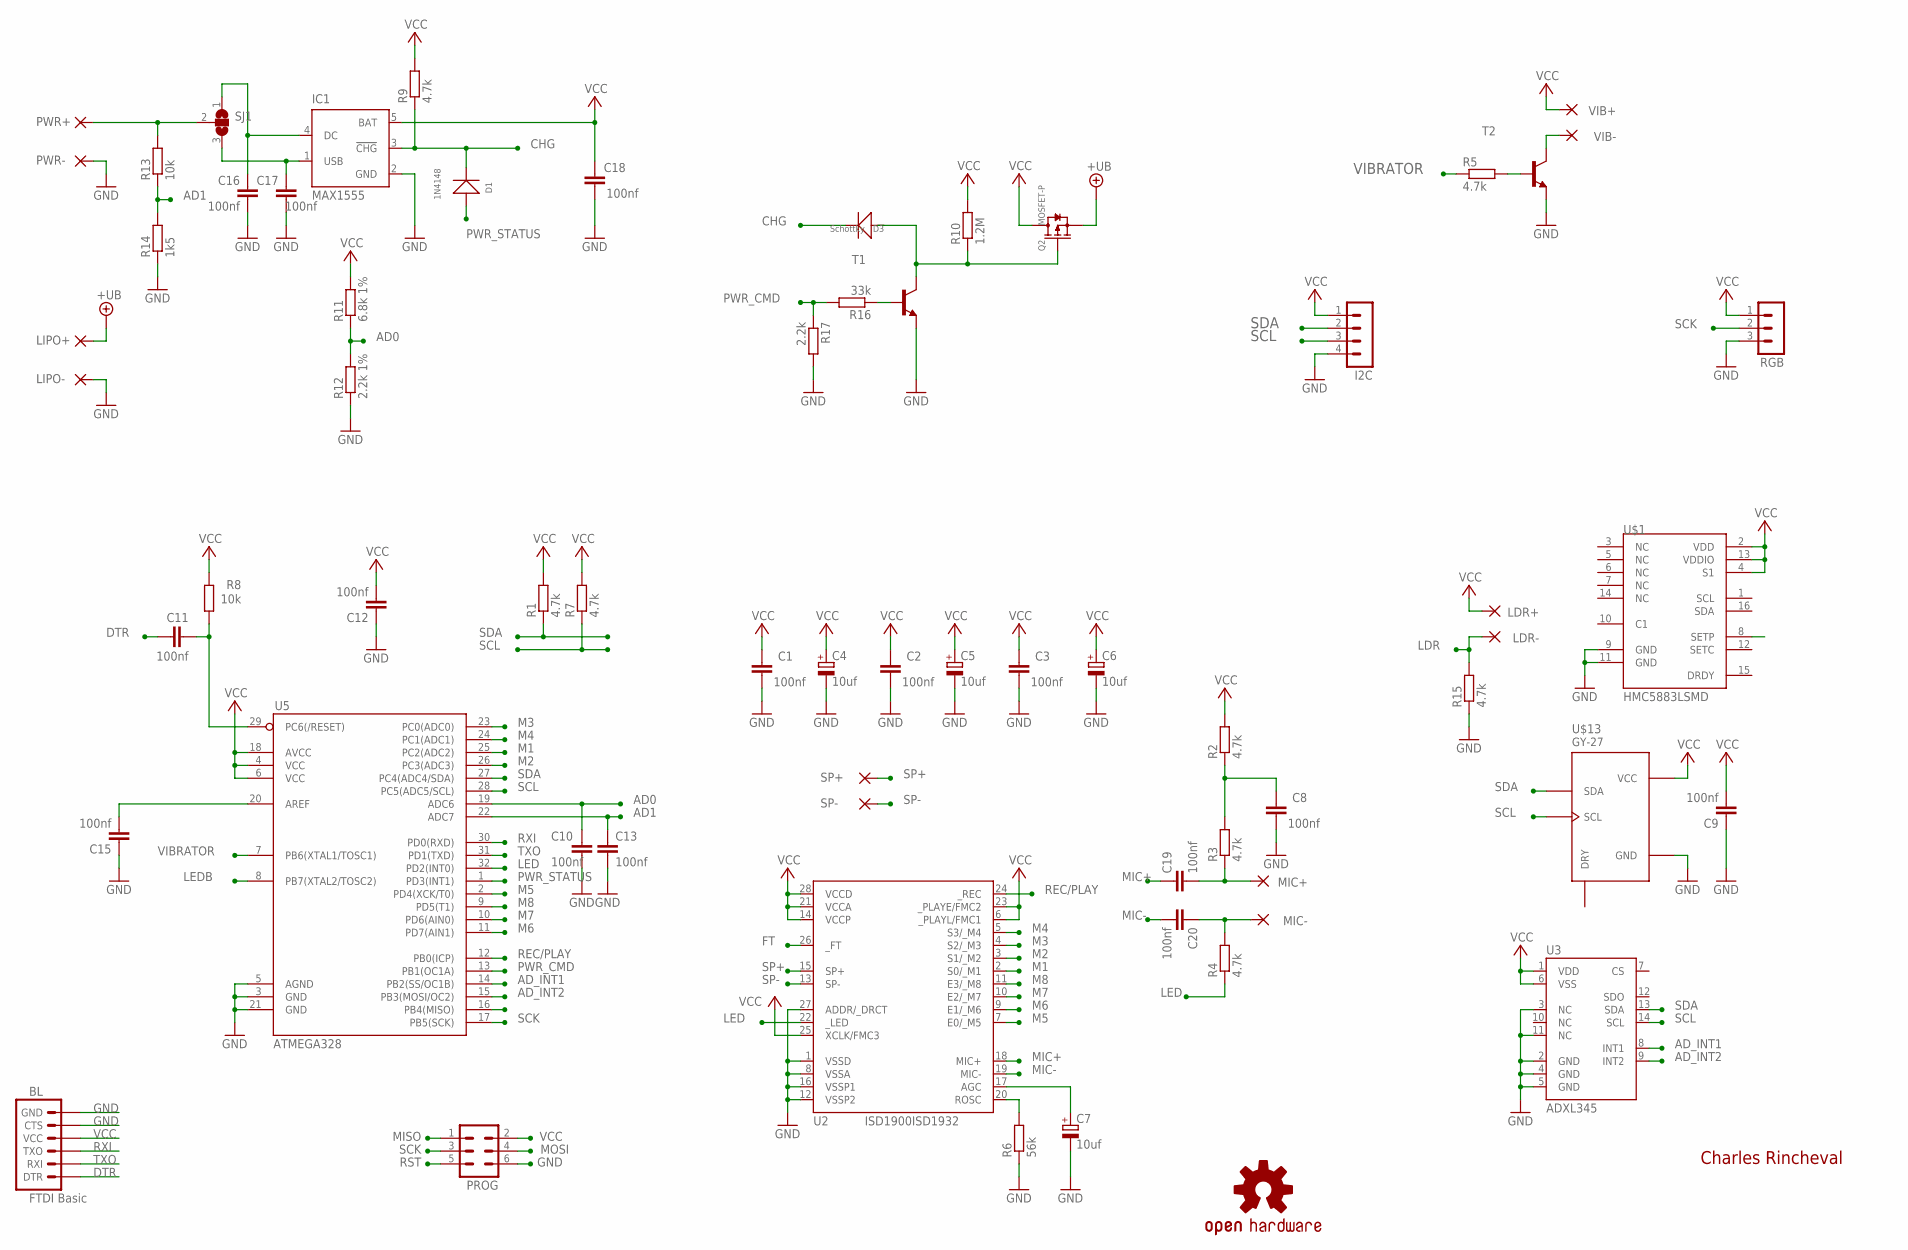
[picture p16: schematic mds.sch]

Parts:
BL: FTDI Basic; 1X06
C1, C2, C3, C8, C9, C10, C11, C12, C13, C15, C16, C17, C18, C19, C20: 100nf; C0805
C4, C5, C6, C7: 10uf; CT3528
D1: 1N4148; LL-34
D3: Schottky; LL-34
I2C: MA04-1
IC1: MAX1555; SOT23-5L
LDR+: 1,6/0,8
LDR-: 1,6/0,8
LIPO+: 1,6/0,8
LIPO-: 1,6/0,8
MIC+: 1,6/0,8
MIC-: 1,6/0,8
PROG: MA03-2
PWR+: 1,6/0,8
PWR-: 1,6/0,8
Q2: MOSFET-P; SOT23
R1, R2, R3, R4, R5, R7, R9, R15: 4.7k; M0805
R6: 56k; M0805
R8, R13: 10k; M0805
R10: 1.2M; M0805
R11: 6.8k 1%; M0805
R12: 2.2k 1%; M0805
R14: 1k5; M0805
R16: 33k; M0805
R17: 2.2k; M0805
RGB: MA03-1
SJ1: SJ2W; SJ_2
SP+: 1,6/0,8
SP-: 1,6/0,8
T1, T2: MMBT2222ALT1-NPN-SOT23-BEC; SOT23-BEC
U2: ISD1900ISD1932; SO-28W
U3: ADXL345; LGA14
U5: ATMEGA328; TQFP32-08
U$1: HMC5883LSMD; 16LPCC
U$13: GY-27
U$14: OSHW-LOGOS; OSHW-LOGO-S
VIB+: 1,6/0,8
VIB-: 1,6/0,8

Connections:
+UB: LIPO+.1, Q2.2 (S)
AD0: C10.1, R11.1, R12.2, U5.19 (ADC6)
AD1: C13.1, R13.1, R14.2, U5.22 (ADC7)
AD_INT1: U3.8 (INT1), U5.14 (PB2(SS/OC1B))
AD_INT2: U3.9 (INT2), U5.15 (PB3(MOSI/OC2))
AGC: C7.+, U2.17 (AGC)
AREF: C15.2, U5.20 (AREF)
CHG: D1.C (-), D3.C (-), IC1.3 (!CHG), R9.1
DTR: BL.1 (DTR), C11.1
FT: U2.26 (_FT)
GND: BL.5 (CTS), BL.6 (GND), C1.1, C2.1, C3.1, C4.-, C5.-, C6.-, C7.-, C8.1, C9.1, C10.2, C12.1, C13.2, C15.1, C16.1, C17.1, C18.1, I2C.4, IC1.2 (GND), LIPO-.1, PROG.6, PWR-.1, R6.1, R12.1, R14.1, R15.1, R17.2, RGB.3, T1.E, T2.E, U2.1 (VSSD), U2.8 (VSSA), U2.12 (VSSP2), U2.16 (VSSP1), U2.27 (ADDR/_DRCT), U3.2 (GND), U3.3 (NC), U3.4 (GND), U3.5 (GND), U3.11 (NC), U5.3 (GND), U5.5 (AGND), U5.21 (GND), U$1.9 (GND), U$1.11 (GND), U$13.GND
LDR: LDR-.1, R15.2
LED: R4.1, U2.22 (_LED), U5.32 (PD2(INT0))
LEDB: U5.8 (PB7(XTAL2/TOSC2))
M1: U2.2 (S0/_M1), U5.25 (PC2(ADC2))
M2: U2.3 (S1/_M2), U5.26 (PC3(ADC3))
M3: U2.4 (S2/_M3), U5.23 (PC0(ADC0))
M4: U2.5 (S3/_M4), U5.24 (PC1(ADC1))
M5: U2.7 (E0/_M5), U5.2 (PD4(XCK/T0))
M6: U2.9 (E1/_M6), U5.11 (PD7(AIN1))
M7: U2.10 (E2/_M7), U5.10 (PD6(AIN0))
M8: U2.11 (E3/_M8), U5.9 (PD5(T1))
MIC+: C19.1, U2.18 (MIC+)
MIC-: C20.2, U2.19 (MIC-)
MISO: PROG.1
MOSI: PROG.4
unnamed: R6.2, U2.20 (ROSC)
unnamed: C19.2, MIC+.1, R3.1
unnamed: C20.1, MIC-.1, R4.2
unnamed: R16.1, T1.B
unnamed: R5.2, T2.B
unnamed: C8.2, R2.1, R3.2
unnamed: T2.C, VIB-.1
unnamed: PWR+.1, R13.2, SJ1.2
unnamed: Q2.1 (G), R10.1, T1.C
unnamed: C17.2, IC1.1 (USB), SJ1.3
unnamed: C16.2, IC1.4 (DC), SJ1.1
PWR_CMD: R16.2, R17.1, U5.13 (PB1(OC1A))
PWR_STATUS: D1.A (+), U5.1 (PD3(INT1))
REC/PLAY: U2.24 (_REC), U5.12 (PB0(ICP))
RST: C11.2, PROG.5, R8.1, U5.29 (PC6(/RESET))
RXI: BL.3 (TXO), U5.30 (PD0(RXD))
SCK: PROG.3, RGB.2, U5.17 (PB5(SCK))
SCL: I2C.3, R7.1, U3.14 (SCL), U5.28 (PC5(ADC5/SCL)), U$13.SCL
SDA: I2C.2, R1.1, U3.13 (SDA), U5.27 (PC4(ADC4/SDA)), U$13.SDA
SP+: SP+.1, U2.15 (SP+)
SP-: SP-.1, U2.13 (SP-)
TXO: BL.2 (RXI), U5.31 (PD1(TXD))
VCC: BL.4 (VCC), C1.2, C2.2, C3.2, C4.+, C5.+, C6.+, C9.2, C12.2, C18.2, I2C.1, IC1.5 (BAT), LDR+.1, PROG.2, Q2.3 (D), R1.2, R2.2, R7.2, R8.2, R9.2, R10.2, R11.2, RGB.1, U2.6 (_PLAYL/FMC1), U2.14 (VCCP), U2.21 (VCCA), U2.23 (_PLAYE/FMC2), U2.25 (XCLK/FMC3), U2.28 (VCCD), U3.1 (VDD), U3.6 (VSS), U5.4 (VCC), U5.6 (VCC), U5.18 (AVCC), U$1.2 (VDD), U$1.4 (S1), U$1.13 (VDDIO), U$13.VCC, VIB+.1
VIBRATOR: R5.1, U5.7 (PB6(XTAL1/TOSC1))

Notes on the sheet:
Charles Rincheval

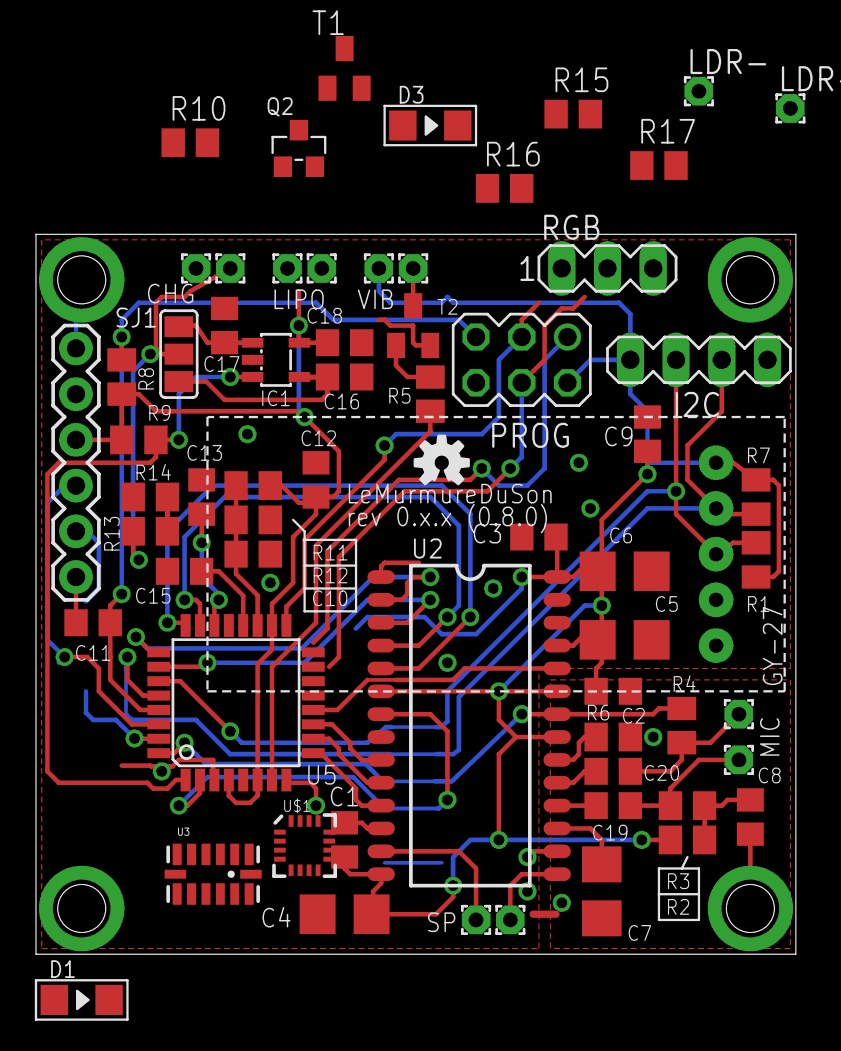
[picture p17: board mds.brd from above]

Board: 2 copper layers, 42.2 x 40.0 mm, 65 parts (0 on the bottom side), 46 nets.

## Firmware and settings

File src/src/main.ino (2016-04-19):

#include <avr/sleep.h>
#include <avr/interrupt.h>
#include <avr/wdt.h>
#include "Wire.h"
//#include <ADXL345.h>
//#include <HL1606strip.h>
#include <SerialCommand.h>
#include "init.h"
//#include "HL1606stripPWM.h"

#define LED_COUNT 6

//#define MUTE

typedef struct {
    char* command;
    void (*function)();
    char* description;
} command;

#ifdef HL1606
HL1606strip strip = HL1606strip(STRIP_D, STRIP_L, STRIP_C, LED_COUNT);

#define BLACK   0b000
#define WHITE   0b111
#define RED     0b100
#define YELLOW  0b101
#define GREEN   0b001
#define TEAL    0b011
#define BLUE    0b010
#define VIOLET  0b110

//HL1606stripPWM strippwm = HL1606stripPWM(LED_COUNT, STRIP_L);

// Last led mapping : 125304

uint8_t Colors[] = {
    RED, YELLOW, GREEN, TEAL, BLUE, VIOLET, WHITE, BLACK
};
#else
Adafruit_NeoPixel strip = Adafruit_NeoPixel(LED_COUNT, STRIP, NEO_GRB + NEO_KHZ800);

#define BLACK   strip.Color(0, 0, 0)
#define WHITE   strip.Color(255, 255, 255)
#define RED     strip.Color(255, 0, 0)
#define YELLOW  strip.Color(255, 255, 0)
#define GREEN   strip.Color(0, 255, 0)
#define TEAL    strip.Color(2, 132, 130)
#define BLUE    strip.Color(0, 0, 255)
#define VIOLET  strip.Color(102, 51, 153)

uint32_t Colors[] = {
    RED, YELLOW, GREEN, TEAL, BLUE, VIOLET, WHITE, BLACK
};
#endif

extern uint8_t Messages[8];
//extern uint8_t Sides[6];

#define MSG_HELLO      6 
#define MSG_CHARGE_OK  7

extern uint8_t Leds[6];

void cmd_help();
void cmd_led();
void cmd_play();
void cmd_record();
void cmd_stop();
void cmd_config();
void cmd_info();
void cmd_demo();
void cmd_color();
void cmd_fstatus();
void cmd_mute();
void cmd_poweron();
void cmd_poweroff();

void unrecognized(const char *);

SerialCommand sCmd;

ADXL345 accel = ADXL345();

Mds mds(strip, accel);

volatile bool tick = false;

uint8_t pattern_demo_rainbow[] = {
    2, 4, 2, 4, 2
};

uint8_t pattern_demo_fade[] = {
    2, 3, 2, 3, 2
};

#define LED_STATUS_ON   ledDelayOn = 0; ledStatus = true;
#define LED_STATUS_OFF  ledDelayOn = 0; ledStatus = false;

unsigned int ledDelayOn = 0;
bool ledStatus = false;

void setLed(uint8_t index, uint32_t color) {
    mds.ledsBrightness(255);
    mds.ledOn(index, color);

    LED_STATUS_ON
}

void setLeds(uint32_t color) {
    mds.ledsBrightness(255);
    mds.ledsColor(color);

    LED_STATUS_ON
}

void fadeIn(uint32_t color) {
    setLeds(color);
    for (uint8_t c = 1; c < 255; c++) {
        mds.ledsBrightness(c);
        delay(2);
    }
}

void fadeOut() {
    for (uint8_t c = 255; c > 0; c--) {
        mds.ledsBrightness(c);
        delay(2);
    }
    mds.ledsBrightness(0);
    ledStatus = false;
}

void ledsOff() {
    mds.ledsOff();

    LED_STATUS_OFF
}

void cplay(uint8_t index) {
    //Serial.print(mds.position.largest);
    PPSTR("Play msg #");
    PLN(index);

    //mds.ledsColor(WHITE);
    setLeds(WHITE);

    // Side led on, play !
    //mds.ledOn(Leds[mds.event.current_side], Colors[mds.event.current_side]);
    //mds.ledOn(Leds[mds.event.current_side], BLUE);
    setLed(Leds[index], BLUE);
}

void crecord(uint8_t index) {
    ledsOff();

    if (index < LED_COUNT) {
        setLed(Leds[index], RED);
//        mds.ledsBrightness(5);
    }
}

void cstop() {
    //mds.ledsColor(WHITE);
    setLeds(WHITE);
}

void powerOff(void) {
    // Todo: Stop Watchdog
    fadeOut();
    PPSTRLN("Power down !");
    wdt_reset();
    delay(2000);
    PPSTRLN("Suicide !");
    wdt_reset();
    delay(200);
    mds.powerOff();
    wdt_reset();
    delay(2000);
}

void breathing(uint8_t cycle, uint8_t _delay) {
    uint8_t c = 1;
    uint8_t upper = true;
    for (; cycle > 0; cycle--) {
        for (uint8_t i = 0; i < 255; i++) {
            mds.ledsBrightness(c);
            delay(_delay);

            wdt_reset();

            if ((!upper && c == 1) || c == 255) {
                upper = !upper;
            }
            c = (upper) ? c + 1 : c - 1;
        }
    }
}

void watchdogOn() {
    // Clear the reset flag, the WDRF bit (bit 3) of MCUSR.
    MCUSR = MCUSR & B11110111;
      
    // Set the WDCE bit (bit 4) and the WDE bit (bit 3) 
    // of WDTCSR. The WDCE bit must be set in order to 
    // change WDE or the watchdog prescalers. Setting the 
    // WDCE bit will allow updtaes to the prescalers and 
    // WDE for 4 clock cycles then it will be reset by 
    // hardware.
    WDTCSR = WDTCSR | B00011000; 

    // Set the watchdog timeout prescaler value to 1024 K 
    // which will yeild a time-out interval of about 8.0 s.
    WDTCSR = B00100001;

    // Enable the watchdog timer interupt.
    WDTCSR = WDTCSR | B01000000;
    MCUSR = MCUSR & B11110111;
}

command commands[] = {
    { "help",       cmd_help,       "Help !" },
    { "?",          cmd_help,       "Help !" },

    { "led",        cmd_led,        "Power on led" },
    { "play",       cmd_play,       "Play sound" },
    { "record",     cmd_record,     "Record sound" },
    { "stop",       cmd_stop,       "Stop" },
    { "config",     cmd_config,     "Read config" },
    { "info",       cmd_info,       "Get info" },
    { "demo",       cmd_demo,       "Run demo" },
    { "color",      cmd_config,     "Color" },
    { "fstatus",    cmd_fstatus,    "Set face" },
    { "mute",       cmd_mute,       "Toggle mute" },
    { "bug",        cmd_bug,        "Test" },
    { "on",         cmd_poweron,    "Power on" },
    { "off",        cmd_poweroff,   "Power off" }
};

void cmd_help() {
    PPSTRLN("Commands list :");
    for (uint8_t i = 0; i < sizeof(commands) / sizeof(command); i++) {
        PPSTR("- ");
        P(commands[i].command);
        PPSTR(" ");
        PLN(commands[i].description);
    }
}
#include <avr/power.h>
#include <avr/sleep.h>
void setup()
{
    Serial.begin(9600);

    sCmd.setDefaultHandler(unrecognized);
    for (uint8_t i = 0; i < sizeof(commands) / sizeof(command); i++) {
        sCmd.addCommand(commands[i].command, commands[i].function);
    }

    //Adafruit_NeoPixel strip = Adafruit_NeoPixel(60, STRIP_C, NEO_GRB + NEO_KHZ800);
    strip.begin();
    strip.show(); // Initialize all pixels to 'off'

    mds.init();

#ifdef MUTE
    mds.mute(true);
#endif

    ledsOff();

    // Battery save !
    if (mds.getBatteryState() > BATTERY_STATE_LOW) {
        setLeds(WHITE);
    }

    mds.setCallbacks(cplay, crecord, cstop);
/*
    strippwm.setPWMbits(5);
    strippwm.setSPIdivider(32);
    strippwm.setCPUmax(80);
*/

    //pos_reset();

//    interrupts(); // enable all interrupts
//    return;

    // initialize timer1
    noInterrupts(); // disable all interrupts
    TCCR1A = 0;
    TCCR1B = 0;

    TCNT1 = 0;//34286; // preload timer 65536-16MHz/256/2Hz
    TCCR1B |= (1 << CS11); // 256 prescaler
    TIMSK1 |= (1 << TOIE1); // enable timer overflow interrupt

    interrupts(); // enable all interrupts

    mds.play(MSG_HELLO);
    delay(2000);

    //wdt_enable(WDTO_2S);
    watchdogOn();

    PPSTRLN("Starting sketch !");
}

ISR(TIMER1_OVF_vect)
{
    //TCNT1 = 0; // reset timer ct to 130 out of 255
    //TCNT1 = 34286; // preload timer
    TCNT1 = 0; // preload timer
    //TIFR1 = 0x100; // timer2 int flag reg: clear timer overflow flag

    tick = true;
}

double data[10];
uint8_t data_index = 0;
double result = 0;

bool lastChargingStatus = false;
uint8_t statusWhenStandOnCharger = BATTERY_STATE_UNKNOW;

int x, y, z;
void loop() {

    while (!tick) {
        sCmd.readSerial();
        delay(1);
    }

    // Stop timer 1 overflow
    TIMSK1 ^= (1 << TOIE1);

    // Led on ?
    if (ledStatus && ledDelayOn++ > 400) {
        fadeOut();
    }
    
    if (!mds.isOnCharger() && !ledStatus && ledDelayOn++ > 4000) {
        PPSTRLN("Off");
        powerOff();
        while(1);
    }

    // Test battery
    switch (mds.getBatteryState()) {
        case BATTERY_STATE_FULL:
        case BATTERY_STATE_LOW:
            break;
        case BATTERY_STATE_CRITICAL:
            ledsOff();
            PPSTRLN("Battery voltage critical : Charge me !");
            delay(500);
            break;
        case BATTERY_STATE_STOP:
            powerOff();
            return;
    }

    if (mds.isOnCharger()) {

        // Cube just be on the charger
        if (!lastChargingStatus) {
            statusWhenStandOnCharger = mds.getBatteryState();
            PPSTR("Cube just be on charger, status : ");
            PLN(statusWhenStandOnCharger);
            if (mds.isCharging() && statusWhenStandOnCharger <= BATTERY_STATE_LOW) {
                fadeIn(RED);
            } else {
                fadeIn(WHITE);
                //breathing(10, 3);
                //fadeIn(WHITE);
            }
        }

        lastChargingStatus = true;

        // Reset event
        //mds.event.processed = false;
        goto lesgotocaimal;
    } else {
        // If last time, charger is in progress
        if (lastChargingStatus) {
            fadeOut();

            if (statusWhenStandOnCharger < BATTERY_STATE_FULL) { 
                mds.play(MSG_CHARGE_OK);
            }
        }

        lastChargingStatus = false;
    }

    mds.detectEvent();

    if (!mds.event.processed) {

        /*
        if (mds.isRecording()) {
            mds.event.processed = true;
//Serial.print("skip");
            return;
        }
        */

        // Play mode
        if (mds.event.validated) {

            if (mds.isRecording()) {
                Serial.print("Stop recording !");
                mds.stop();
            }

            mds.play(mds.event.current_side);

            mds.event.processed = true;
        }
    } else {

        if (mds.event.shaked) {
            if (mds.isRecording()) {
                Serial.print("Stop recording !");

                mds.stop();
            } else {

                mds.vibrate(150);
                delay(500);
                mds.vibrate(150);
                delay(500);
                mds.vibrate(150);
                delay(500);

                Serial.print("Record msg #");
                Serial.print(mds.event.current_side);

                mds.record(mds.event.current_side);

                // 6 seconds later, stop !
                //delay(mds.config.msgDuration);
            }

            mds.event.shaked = false;
            mds.event.shaked_counter = 0;
            //mds.event.processed = true;
        }

        /*
        // Record mode
        if (mds.event.shaked) {
Serial.print("shaked");
            if (mds.isRecording()) {
                mds.stop();

                mds.resetEvent();
                mds.event.processed = true;

                Serial.println(" Stop !");

                // Vibrate, led off !
                //mds.vibrate(200);
                mds.ledsOff();

                mds.event.processed = false;
            } else {
                P("Shake detected !");
                mds.vibrate(50);

                Serial.print("Record msg #");
                Serial.print(mds.event.current_side);

                // Side led on and vibrate !
                mds.ledOn(Leds[mds.event.current_side], RED);
                //mds.vibrate(200);

                // Start record
                mds.record(mds.event.current_side);

                mds.resetEvent();
                mds.event.processed = true;

                // 6 seconds later, stop !
                //delay(mds.config.msgDuration);
            }
        }
        */
    }

    // Test pattern
    if (mds.testPath(pattern_demo_rainbow, sizeof(pattern_demo_rainbow))) {

        for (int i = 0; i < 10; i++) {
            mds.vibrate(50);
            mds.rainbowParty(100);
        }

        memset(mds.path, 0x00, sizeof(mds.path));
        fadeIn(WHITE);
    } else if (mds.testPath(pattern_demo_fade, sizeof(pattern_demo_fade))) {

        for (int i = 0; i < sizeof(Colors) / sizeof(WHITE); i++) {
            fadeOut();
            fadeIn(Colors[i]);
        }

        memset(mds.path, 0x00, sizeof(mds.path));
        fadeIn(WHITE);
    }


lesgotocaimal:
    wdt_reset();
    tick = false;
    TIMSK1 |= (1 << TOIE1);
}

/*
    mds.accel.getInterruptSource();

    if (mds.accel.isActivitySourceOnX()) {
        Serial.print("isActivitySourceOnX(): ");
        Serial.println(mds.accel.isActivitySourceOnX(), DEC);
    }

    if (mds.accel.isActivitySourceOnY()) {
        Serial.print("accel.isActivitySourceOnY(): ");
        Serial.println(mds.accel.isActivitySourceOnY(), DEC);
    }

    if (mds.accel.isActivitySourceOnZ()) {
        Serial.print("mds.accel.isActivitySourceOnZ(): ");
        Serial.println(mds.accel.isActivitySourceOnZ(), DEC);
    }

    if (mds.accel.isTapSourceOnX()) {
        Serial.print("mds.accel.isTapSourceOnX(): ");
        Serial.println(mds.accel.isTapSourceOnX(), DEC);
    }

    if (mds.accel.isTapSourceOnY()) {
        Serial.print("mds.accel.isTapSourceOnY(): ");
        Serial.println(mds.accel.isTapSourceOnY(), DEC);
    }

    if (mds.accel.isTapSourceOnZ()) {
        Serial.print("mds.accel.isTapSourceOnZ(): ");
        Serial.println(mds.accel.isTapSourceOnZ(), DEC);
    }

    //delay(500);
*/

void cmd_led() {
    char *arg;
    unsigned int index, color = 0;

    arg = sCmd.next();
    if (!strcmp(arg, "set")) {
        arg = sCmd.next();
        index = atoi(arg);
        if (index < 0 || index >= sizeof(Leds)) {
            PPSTRLN("Index range : 0...7");
        } else {
            PPSTR("Set led ");
            P(index);

            arg = sCmd.next();
            color = atoi(arg);
            if (index < 0 || index >= sizeof(Colors)) {
                PPSTRLN("Color range : 0...5");
            return;
            }

            PPSTR(" to color ");
            P(color);

            setLed(Leds[index], Colors[color]);

            PLN("");
        }
    } else if (!strcmp(arg, "all")) {
        arg = sCmd.next();
        color = atoi(arg);
        if (index < 0 || index >= sizeof(Colors)) {
            PPSTRLN("Color range : 0...5");
            return;
        }

        PPSTR("Set all led to color ");
        P(color);

        //mds.ledsColor(Colors[color]);
        setLeds(Colors[color]);
        PLN("");
    } else if (!strcmp(arg, "off")) {
        
        fadeOut();
        PPSTRLN("Leds off !");

    } else if (!strcmp(arg, "fade")) {
       
        PPSTR("Fade leds ");
        P(index);

        arg = sCmd.next();
        color = atoi(arg);
        if (index < 0 || index >= sizeof(Colors)) {
            PPSTRLN("Color range : 0...5");
            return;
        }

        PPSTR(" to color ");
        PLN(color);

        fadeOut();
        fadeIn(Colors[color]);

    } else if (!strcmp(arg, "bright")) {
        arg = sCmd.next();
        color = atoi(arg);

        PPSTR("Set leds brightness to ");
        PLN(color);

        mds.ledsBrightness(color);

    } else if (!strcmp(arg, "map")) {

        arg = sCmd.next();
        if (!strcmp(arg, "get")) {
            arg = sCmd.next();
        
            PPSTR("Mapping : ");

            for (int i = 0; i < sizeof(Leds); i++) {
                P(Leds[i]);
            }

            PLN("");
        
        } else if (!strcmp(arg, "set")) {
            arg = sCmd.next();
            //index = atoi(arg);

            for (int i = 0; i < sizeof(mds.config.ledMapping); i++) {
                mds.config.ledMapping[i] = arg[i] - ((int)'0');
                Leds[i] = mds.config.ledMapping[i];
            }

            mds.saveConfig();
            PPSTR("New mapping set to ");
            PLN(arg);
        }
    } else {
        PPSTRLN("Unknow command !");
        PPSTRLN("Commands : set, all, off, fade, bright, map");
    }
}

void cmd_color() {
    char *arg;
    unsigned int index, color = 0;

    arg = sCmd.next();
    color = atoi(arg);
    if (index < 0 || index >= sizeof(Colors)) {
        PPSTRLN("Color range : 0...5");
    }

    PPSTR("Set color ");// (RED, YELLOW, GREEN, TEAL, BLUE, VIOLET,  WHITE, BLACK) ");
    PLN(color);

    //mds.ledsColor(Colors[color]);
    setLeds(Colors[color]);
}

void cmd_play() {
    char *arg;
    unsigned int index = 0;

    arg = sCmd.next();
    index = atoi(arg);
    if (index < 0 || index >= sizeof(Messages)) {
        PPSTRLN("Index range : 0...7");
    } else {
        PPSTR("Play ");
        P(index);

        mds.play(index);
        //delay(6000);
        //mds.stop();

        PPSTRLN("...Stop");
    }
}

void cmd_stop() {
    mds.stop();
    PPSTRLN(" Stop");
}

void cmd_record() {
    char *arg;
    unsigned int index = 0;
    uint8_t i = 0;

    arg = sCmd.next();
    index = atoi(arg);
    if (index < 0 || index >= sizeof(Messages)) {
        PPSTRLN("Index range : 0...7");
    } else {
        PPSTR("Record ");
        P(index);
        PPSTR(" : ");

        for (i = 3; i > 0; i--) {
            PPSTR(" ");
            P(i);
            wdt_reset();
            delay(1000);
        }

        PPSTR(" : Speak !");

        mds.record(index);

        wdt_reset();
        delay(mds.config.msgDuration);
        mds.stop();

        PPSTRLN("...Stop");
    }
}

void cmd_config() {
    int i = 0;
    char *arg;
    arg = sCmd.next();
    if (!strcmp(arg, "read")) {
        PPSTRLN("Murmure Du Son");
        PPSTR("version     : ");
        PLN(mds.config.version);
        PPSTR("msgDuration : ");
        PLN(mds.config.msgDuration);
        PPSTR("ledMapping  : ");
        for (i = 0; i < sizeof(mds.config.ledMapping); i++) {
            P((char)(mds.config.ledMapping[i] + ((int)'0')));
        }
        PPSTRLN("");
    } else if (!strcmp(arg, "default")) {
        strcat(mds.config.version, MDS_VERSION);
        mds.config.msgDuration = MSG_DURATION;
        mds.config.debugMode = DEBUG_MODE;
        mds.saveConfig();
        PPSTRLN("Default config saved !");
    } else if (!strcmp(arg, "set")) {
        arg = sCmd.next();

        if (!strcmp(arg, "msgDuration")) {
            arg = sCmd.next();
            mds.config.msgDuration = atoi(arg);
            mds.saveConfig();
            PPSTRLN("msgDuration saved !");
        } else {
            PPSTRLN("Unknow var !");
        }
    } else {
        PPSTRLN("Arg not found !\n\r - config [read|default|set]");
    }
}

void cmd_info() {
    double data[3];
    int error = 0;
    float headingDegrees, heading;
    char *arg;
    arg = sCmd.next();

    error = mds.compass.SetScale(1.3);
    if (error != 0) {
        //Serial.println(mds.compass.GetErrorText(error));
    }

    error = mds.compass.SetMeasurementMode(Measurement_Continuous);
    if (error != 0) {
        //Serial.println(mds.compass.GetErrorText(error));
    }

    while (true) {

        if (Serial.read() == 13) {
            break;
        }
        /*
        //while (Serial.available() > 0) {
            if (Serial.read() == '\n') {
                break;
                //return;
            }
        //}
        */

        PPSTRLN("[Power]");
        PPSTR(" Battery : ");
        P(mds.getBatteryVoltage());
        PPSTRLN("V");

        PPSTR(" Status  : ");
        switch (mds.getBatteryState()) {
            case BATTERY_STATE_FULL:
                PPSTRLN("Full");
                break;
            case BATTERY_STATE_LOW:
                PPSTRLN("Low");
                break;
            case BATTERY_STATE_CRITICAL:
                PPSTRLN("Critical");
                break;
            case BATTERY_STATE_STOP:
                PPSTRLN("Stop");
                break;
        }

        PPSTR(" Charge  : ");
        if (mds.isOnCharger()) {
            if (!mds.isCharging()) {
                PPSTRLN("Standby");
            } else {
                PPSTRLN("In progress");
            }
        } else {
            PPSTRLN("None");
        }

        PPSTR(" On charger : ");
        if (mds.isOnCharger()) {
            PPSTRLN("True");
        } else {
            PPSTRLN("False");
        }

        PPSTR(" Charger : ");
        P(mds.getChargerVoltage());
        PPSTRLN("V");

        MagnetometerRaw raw = mds.compass.ReadRawAxis();
        heading = atan2(raw.YAxis, raw.XAxis);

        // Correct for when signs are reversed.
        if (heading < 0) {
            heading += 2 * PI;
        }

        PPSTRLN("\n[Sensor]");
        PPSTR(" Magnetometer : ");
        P(heading * 180 / M_PI);
        PPSTRLN(" degree");

/*
        PPSTR("Magnetometer x:");
        P(raw.XAxis);
        PPSTR(", y:");
        P(raw.YAxis);
        PPSTR(", z:");
        PLN(raw.ZAxis);
*/

        accel.get_Gxyz(data);
        PPSTR(" Accel x:");
        P(data[0]);
        PPSTR(", y:");
        P(data[1]);
        PPSTR(", z:");
        PLN(data[2]);

        PPSTR(" Temp : ");
        PLN(mds.getTemperature());

        if (strcmp(arg, "loop")) {
            break;
        }

        PPSTRLN("--");

        delay(1000);
        wdt_reset();
    }

    PPSTRLN("End");
}

void unrecognized(const char *command) {
    PPSTR("'");
    P(command);
    PPSTRLN("' command not found !");
}
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

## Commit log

2013-06-25 First dev
    [mds.brd, mds.sch]
2013-06-27 Schema development
    [mds.brd, mds.sch]
2013-07-01 Schema + PCB
    [mds.brd, mds.sch]
2013-07-08 Modif PCB - rev 0.5.1
    [mds.brd, mds.sch]
2013-07-18 PCB Version 0.6.2
    [mds.GBL, mds.GBO, mds.GBP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]
2013-08-04 Code + Doc + OpenScad
    [cube.scad, cube.stl, cube_first.stl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]
2013-08-05 OpenScad work
    [cube.scad, cube.stl, cube_first.stl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]
2013-08-05 OpenScad works
    [cube.scad]
2013-08-07 Parabole (OpenScad)
    [cube.scad]
2013-08-24 Code !
    [cube.backup.scad, mds.brd, mds.sch]
2013-08-29 Code + Cad
    [cube.scad, mds.brd, mds.sch]
2013-09-02 PCB : Bluetooth module + enhancement
    [cube.scad, mds.brd, mds.sch]
2013-09-04 Stl file + PCB
    [0.stl, 1.stl, 2.stl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]
2013-09-11 PCB 0.8.0
    [cube.scad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]
2013-09-30 SCad, Texture
    [cube.scad, mds.brd, support.stl]
2013-10-01 Texture + Code hardware 0.8.0
    [0.stl, cube.scad, mds.brd]
2013-10-02 Bump mapping
    [1.stl, 2.stl, 3.stl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]
2013-10-07 Clean, code, openscad
    [0.stl, 1.stl, 2.stl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]
2013-10-09 Cad, export
    [pattern.scad]
2013-10-13 Code, Cad
    [base_enveloppe_cable.stl, base_plate_cable.stl, cube.scad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]
2013-10-30 Update !
    [0.stl, 1.stl, 2.stl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]
2013-11-06 Message
    - MAX_BRIGHTNESS
    - Welcome message
    - Charged message
    [cube.scad, mds.brd, mds.sch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]
2013-11-19 Power control
    [mds.brd, mds.sch]
2013-11-19 Modif schéma
    [mds.sch]
2014-03-25 Debug + WatchDog
    [charger.scad]
2016-04-19 Update CAD
    [mds.brd, mds.sch]
2016-04-19 New version 2 in progress
    [mds2.brd, mds2.sch]
2016-05-07 Work on Schematic / PCB
    [mds2.brd, mds2.sch]
2016-07-04 Add 2.0.0 PCB gerber files
    [mds2.GBL, mds2.GBO, mds2.GBP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]
2016-07-04 Remove 0.8.0 gerber archive
2016-07-04 Add PCB 2.0.0
    [mds2.brd, mds2.sch]

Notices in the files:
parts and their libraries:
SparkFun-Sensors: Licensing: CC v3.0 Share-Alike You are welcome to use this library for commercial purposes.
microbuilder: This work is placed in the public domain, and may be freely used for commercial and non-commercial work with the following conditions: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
